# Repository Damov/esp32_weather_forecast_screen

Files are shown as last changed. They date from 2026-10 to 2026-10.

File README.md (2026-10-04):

# ESP32 weather forecast screen

A desktop weather display built around a 4-inch ESP32 touchscreen. It shows the local time, current weather and daily and hourly forecasts from Open-Meteo. The project includes Rust firmware for the Freenove FNK0103S display with an ESP32-WROOM-32E module, plus a 3D-printable enclosure and stand. An optional HLK-LD2410C radar detects presence to wake the screen.

The firmware was created using AI and agentic coding tools under human supervision.

<p align="center">
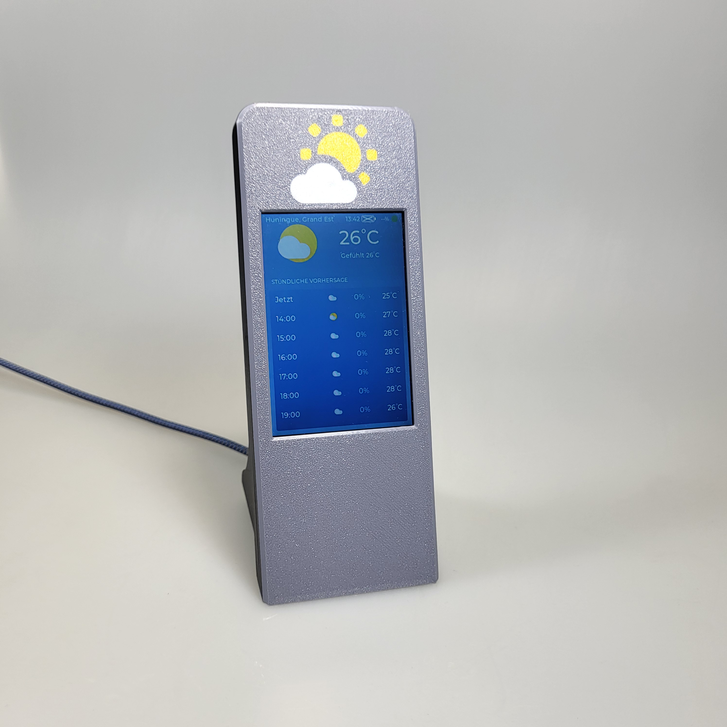
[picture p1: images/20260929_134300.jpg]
Weather display in its printed enclosure and stand

</p>

The photograph shows the assembled display running an older version of the firmware. The screenshots below show the current interface with example data.

## The interface

The 320 × 480 portrait display has a blue gradient background, white Montserrat text and darker blue weather panels. The Clock page combines an analogue dial with digital time and a local date. A rounded card below shows the weather symbol, current temperature and feels-like temperature.

The Week page shows today and the next six days, with weather symbols, precipitation probabilities and minimum and maximum temperatures. The Hours page shows the next seven hourly forecasts, with temperatures and precipitation probabilities. Both fit seven rows on the screen without scrolling. A settings gear and weather source credit sit at the bottom of each page.

<p align="center">
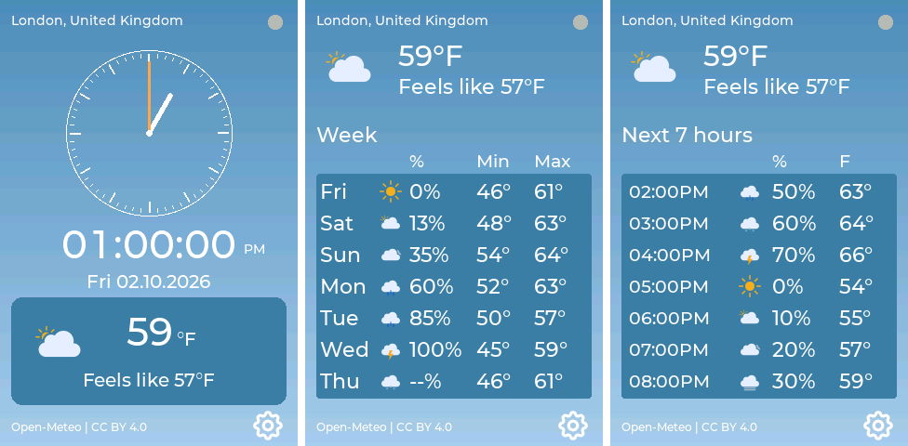
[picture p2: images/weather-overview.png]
Current Clock, Week and Hours pages, from left to right

</p>

## Printing, assembly and use

The [printing and assembly guide](printable_3D_model/README.md) includes the model files, parts list, print settings and radar wiring. The [illustrated user guide](USER_GUIDE.md) covers firmware installation, first startup, Wi-Fi, touchscreen controls, location search and settings.

## Building on Linux

Install [Rust with rustup](https://rustup.rs/) and the Linux host dependencies listed in the [esp-rs prerequisites](https://github.com/esp-rs/esp-idf-template#generate-the-project), including CMake, Ninja, Python and libclang. Then install the ESP32 toolchain and linker proxy:

```sh
cargo install espup --locked
espup install
cargo install ldproxy --locked
```

In each build shell, load the environment created by espup. Its default path is:

```sh
. "$HOME/export-esp.sh"
```

From the repository root, build the release firmware:

```sh
./build.sh
```

The project selects the `esp` Rust toolchain, the `xtensa-esp32-espidf` target and ESP-IDF `v5.5.5`. The first build needs internet access to download the SDK and tools. Use a shell without an `IDF_PATH` override so the pinned SDK is used.

The release ELF is written to `firmware/target/xtensa-esp32-espidf/release/weather-forecast-firmware`. The script forwards extra Cargo arguments, such as `./build.sh --locked` once `firmware/Cargo.lock` exists. It only builds the software.

See the [firmware README](firmware/README.md) for implementation details, host tests, asset generation and documentation previews. Installation steps are in the [user guide](USER_GUIDE.md#installing-the-firmware-under-linux).

To inspect or remove build output and temporary files:

```sh
./clean.sh --dry-run
./clean.sh
./clean.sh --all --dry-run
./clean.sh --all
```

Default cleanup removes Cargo build output, mutation-test output, Python bytecode caches, Rust backup files, `.pdb` files, and generated or old `sdkconfig` files. Tracked files, secrets, backups, and symlinks are preserved. `--all` also removes local `.embuild` SDK caches and the documented `/tmp/weather-wifi-preview` and `/tmp/weather-assets-venv` directories; the next build may download the SDK and tools again. Custom preview destinations and other files under `/tmp` are retained. The script works from any working directory and requires Bash and Git, without requiring Cargo. Run it when builds and preview generators are stopped.

## Building on Windows

**TODO:** To be written in near future!

## Licences and credits

The firmware source code is licensed under [MIT](LICENSE). Third-party components retain their own licences. This project was inspired by [Aura](https://github.com/Surrey-Homeware/Aura).

As of the MIT relicensing change on 4 October 2026, the project's own code is available under MIT. Earlier versions were published under GPL-3.0-only; rights already granted under that licence remain in effect. Third-party code and assets retain their respective licences.

- **Fonts:** [Montserrat](https://github.com/JulietaUla/Montserrat) by Julieta Ulanovsky and contributors (OFL-1.1), using [LVGL](https://github.com/lvgl/lvgl) font source material (MIT).
- **Symbols:** [Meteocons](https://github.com/basmilius/meteocons) by Bas Milius and [Tabler Icons](https://github.com/tabler/tabler-icons) by Paweł Kuna (MIT).
- **Display:** ST7796 initialization adapted from [TFT_eSPI](https://github.com/Bodmer/TFT_eSPI/tree/V2.5.43) by Bodmer (MIT/BSD).
- **Platform:** [ESP-IDF](https://github.com/espressif/esp-idf/tree/v5.5.5) and Rust libraries listed in the [dated dependency CSV](docs/third-party-rust-2026-10-04.csv). ESP32 Wi-Fi and PHY require precompiled Espressif libraries without publicly available complete implementation source.
- **HTTPS certificates:** [Mozilla CA certificate data](https://curl.se/docs/caextract.html) (MPL-2.0).
- **Weather and locations:** [Open-Meteo](https://open-meteo.com/) and [GeoNames](https://www.geonames.org/) (data attribution under CC BY 4.0). Open-Meteo's free API has [non-commercial service terms](https://open-meteo.com/en/terms).

See the [third-party declaration dated 4 October 2026](docs/third-party-declaration-2026-10-04.md) for sources, versions, licences and attribution details.

Binary firmware distributions must include the accompanying third-party notices and required source materials. See the [release licensing workflow](docs/FIRMWARE_RELEASE_LICENSES.md) for the collected notices, offline checks, local packaging and automatic GitHub releases on version tags.

## TODO

- [ ] Reuse the display’s BOOT button to trigger screen recalibration.
- [ ] Add a complete factory reset capability using the display’s RST button.

# Disclaimer

<b>This project and all associated files, documentation, and source code are provided “as is” without any express or implied warranties, including but not limited to the implied warranties of merchantability, fitness for a particular purpose, and non‑infringement. The author and contributors of this repository assume no responsibility or liability for any direct, indirect, incidental, or consequential damages that may occur through the use, modification, or distribution of the software and hardware designs contained herein. This includes, but is not limited to, hardware damage, data loss, malfunctioning devices, or personal injury that may arise from incorrect wiring, improper configuration, or misuse of the provided code and documentation. Users are encouraged to review, test, and verify all code before deploying it on any system. If you choose to use this project, you do so entirely at your own risk. By downloading, copying, modifying, or using any part of this project, you acknowledge that you have read, understood, and agree to this disclaimer.

The HLK-LD2410C radar module’s CE status is unknown to this project. The existence of an EU declaration of conformity or US regulatory compliance documentation has not been verified. Check your local laws and regulatory requirements before using the radar. Use it at your own risk.</b>

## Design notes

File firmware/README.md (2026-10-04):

# Firmware development

This directory contains the Rust application, using ESP-IDF with standard-library support. See the [main README](../README.md#building-on-linux) for the Linux build and the [user guide](../USER_GUIDE.md) for installation and device operation. The [assembly guide](../printable_3D_model/README.md) covers physical wiring.

Run the commands in this document from the repository root.

For binary distribution, use the [release licensing workflow](../docs/FIRMWARE_RELEASE_LICENSES.md) to check the original third-party notices and package them with the firmware.

## Build layout under Linux

Use `./build.sh` for device builds. It resolves `firmware/partitions.csv` to an absolute path in `firmware/target/esp32-partitions.sdkconfig`. That generated file supplies only the partition filename. `firmware/sdkconfig.defaults` supplies the remaining settings. Host tests and previews can use Cargo directly.

The build script forwards Cargo arguments and can be invoked by its path from another directory. Keep `firmware/Cargo.lock` in Git once generated for reproducible dependency resolution. Assets are checked in, so a normal device build does not need the font or icon conversion tools.

## Settings storage and compatibility

The versioned JSON profile is stored in NVS namespace `app_settings`, key `profile`, separately from Wi-Fi credentials and `touch_cal`. If no profile exists, the firmware reads compatible values from the legacy `weather` namespace without modifying its keys. The first preference change saves the imported profile. An imported location with no timezone is resolved online. No night schedule is applied until its timezone is known. Unreadable profiles show an error and disable preference writes without erasing storage.

Older version-1 profiles without the presence-wake field default to enabled. The legacy `weather/wakePresence` value is imported when available. Disabling wake changes backlight behaviour without stopping sensing or indicator updates.

## Backlight and time scheduling

**Screen off after** offers Never, 1, 5, 10, or 30 minutes. Inactivity uses a monotonic timer: touch, enabled radar presence, and calibration restart it. Background Wi-Fi traffic, clock updates, and HTTP responses do not. Calibration also keeps the backlight at least half brightness. Changing the timeout restarts the countdown. Old profiles without `sleep_minutes` default to five minutes. Supported timeout values are imported from the legacy `weather/standbyMinutes` key without modifying it.

When the timeout expires, only the LCD backlight turns off. The ESP32, LCD controller, Wi-Fi, radar, clock, and forecast worker keep running, and the screen contents continue updating. Touch or enabled presence restores the saved brightness without restarting the firmware, reconnecting Wi-Fi, or changing the selected page. The waking touch is consumed until release so it does not activate a button. This keeps information immediately available, with higher power consumption than deep sleep. A failed backlight-off write leaves the screen on and retries after 60 seconds. A failed restore leaves it off and allows another activity to retry.

Night mode defines 22:00–06:00 in the selected location's IANA timezone, including DST. With a finite timeout, the same inactivity interval applies day and night. With **Never**, inactivity blanking is disabled, but an enabled night schedule can still turn the backlight off. A touch or enabled presence overrides that night's schedule until the next daytime period is observed. SNTP supplies UTC time after Wi-Fi connects. The night schedule waits for synchronised time and a valid timezone. A dark screen stays dark after 06:00 until touch or enabled presence restores it. The stored `sleep_minutes` key and profile version remain unchanged for compatibility.

## Location search

Search runs in a worker over certificate-verified HTTPS, requesting up to 15 results in the selected language. Select a result and tap **Save** to store its name, coordinates, and IANA timezone. Responses are limited to 32 KiB. The screen times out after 10 seconds and ignores cancelled, stale, or late results. Searches require Wi-Fi and synchronised time. The saved location, timezone, units, language, and clock format apply to all weather views.

## Weather fetching and rendering

Search results save an optional `compact_name` for the city-and-country label. Older profiles remain compatible. For three-part names, weather pages omit the intermediate region. Single names remain unchanged when country information is unavailable. Search and Settings keep the full location name.

All pages use the saved location's IANA timezone, including daylight-saving changes, and honour Celsius/Fahrenheit, 12/24-hour time, and the eight supported languages. The clock waits for synchronised time and a known timezone. It never substitutes UTC for an unresolved local timezone. The six time digits use fixed-width cells centred as one group, so changing digits never shifts the other digits or colons. Seconds repaint only the clock region, without repainting weather, presence, or buttons. Updates compare the previous and new clock contents in two reusable RGB565 strip buffers (18.5 KiB total). Only runs of actually changed pixels are sent to the LCD. Unchanged content causes no display writes. On the Clock page, forecast and status updates also compare finished pixels, reusing the same buffers for the weather card and status line. These updates leave the clocks, location, attribution and settings gear untouched. Week and Hours use the same differential updates for their current weather, status, and seven forecast rows, including hour and date rollovers. Their tables use the Clock weather card's darker blue. Text uses 19/22/31px fonts, with seven entries still visible without scrolling. The shared buffers keep the same 18.5 KiB allocation. Page changes and returns from Settings seed a new snapshot after a complete draw. Failed transfers invalidate the affected snapshot so a subsequent attempt restores that region. There is no visible background-clear pass during these updates and no PSRAM requirement. Settings retains its minute-only clock updates. Clock and HTTP traffic do not reset the inactivity timer.

Forecasts use the [Open-Meteo forecast API](https://open-meteo.com/en/docs) over certificate-verified HTTPS in the existing background worker. The firmware refreshes every ten minutes, retries errors after sixty seconds, and refreshes on reconnection or location change. Responses are limited to 32 KiB and HTTP operations to ten seconds, with a thirty-second application deadline allowing for a queued operation. Eight days of data are fetched to cover midnight rollover, while only seven daily and seven hourly entries are displayed. Temperatures are cached in Celsius and converted locally when units change.

Loading and failed requests have visible messages. Missing values show `--`. Unknown weather codes use a neutral unavailable symbol. Failed refreshes retain the previous same-location forecast and mark it outdated. Data also becomes outdated after twenty minutes without a successful refresh. Expired dates/hours are excluded, and unavailable future entries show placeholders. Changing the location clears the old forecast and ignores late responses. Forecasts are held only in RAM. If Wi-Fi drops, the existing connection status screen returns and reconnects. The selected weather page returns after connection succeeds.

## Weather symbols and UI icons

The white settings gear uses Tabler Icons' **settings** SVG by Paweł Kuna, under the MIT licence. The pinned source, revision, checksum, copyright and full licence are in `firmware/assets/ui/`. `tools/generate_ui_icons.py --check` verifies the generated alpha mask. See [Tabler Icons](https://github.com/tabler/tabler-icons). This symbol licence is separate from the CC BY 4.0 weather-data attribution.

Weather symbols are the static **flat Meteocons** collection by **Bas Milius**: [source repository](https://github.com/basmilius/meteocons), pinned npm package [`@meteocons/svg-static` 0.1.0](https://www.npmjs.com/package/@meteocons/svg-static/v/0.1.0).

**Licence: MIT**, with copyright **(c) 2020-present Bas Milius**. The licence permits free use, modification, embedding, and redistribution, including commercial use, provided the copyright and permission notice are retained.

The symbols retain their MIT licence independently of the MIT firmware. The complete [MIT licence](assets/weather/MIT.txt), [attribution and conversion notice](assets/weather/NOTICE.txt), [source/version/integrity manifest](assets/weather/sources.json), and [SHA-256 asset checksums](assets/weather/checksums.json) are included. Retain MIT.txt and NOTICE.txt with source and binary releases, along with the existing firmware and font notices. Credits do not imply endorsement.

The original SVG subset is retained under `firmware/assets/weather/svg/`. Thirteen symbols cover clear day/night, partly cloudy day/night, overcast, fog, drizzle, freezing precipitation, rain, snow, thunderstorms, thunderstorms with hail, and unavailable conditions. Symbols are converted to 32px forecast and 72px current-weather bitmaps with RGB565 colour and alpha transparency. Their shapes are preserved, and no runtime icon download or SVG library is required.

Regenerate or check assets using **CairoSVG 2.7.1**, **Cairo 1.16.0**, and **Pillow 9.0.1** (Cairo is a system library):

```sh
python3 -m venv --system-site-packages /tmp/weather-assets-venv
/tmp/weather-assets-venv/bin/pip install CairoSVG==2.7.1 Pillow==9.0.1
/tmp/weather-assets-venv/bin/python tools/generate_weather_icons.py
/tmp/weather-assets-venv/bin/python tools/generate_weather_icons.py --check
```

The converter verifies the archive's pinned SHA-512 integrity before reading it. CairoSVG and Pillow are build-time conversion tools with their own licences. They are not linked into the firmware. The clock adds a 42px Montserrat numeric subset under the existing OFL-1.1 font licence, generated by the font tool.

## HLK-LD2410C radar

**The HLK-LD2410C radar module’s CE status is unknown to this project. The existence of an EU declaration of conformity or US regulatory compliance documentation has not been verified. Check your local laws and regulatory requirements before using the radar. Use it at your own risk.**

The Rust receiver implements [Hi-Link’s LD2410C serial protocol V1.09](https://r0.hlktech.com/download/HLK-LD2410C-24G/1/LD2410C%20%E4%B8%B2%E5%8F%A3%E9%80%9A%E4%BF%A1%E5%8D%8F%E8%AE%AE%20V1.09.pdf). Firmware code is licensed under MIT.

| Radar connection | ESP32/display connection |
| --- | --- |
| TX | GPIO35 / GP35, UART1 receive |
| OUT | GPIO32 / P4 SDA, active-high presence input |
| RX | Unconnected. This firmware sends no sensor commands |
| GND | Common display ground |
| VCC | Existing regulated 5 V supply with capacity above 200 mA |

Sensor data lines are 3.3 V logic. UART1 runs at the sensor's factory setting of **256000 baud, 8N1**, leaving the CH340 USB connection on UART0 available for logs and flashing. GPIO39 belongs to the touch controller. UART0 and GPIO39 are not used for radar. The driver initialises after startup calibration and reads in bounded nonblocking batches from a 4096-byte receive buffer. No additional radar library or device configuration is required.

Both basic and engineering reports provide moving/stationary target flags, respective distances in centimetres, energy values, and detection distance. A fixed 64-byte parser validates framing and resynchronises after malformed data. After one second without a valid report, UART connectivity and all measurements are cleared. OUT is evaluated independently: an asserted OUT or a fresh positive UART report counts as presence. An inactive OUT does not override a positive UART report. Empty nonblocking reads retain partial frames. UART read errors clear their measurements and are retried on subsequent loops. Initialisation errors are logged without stopping the UI, and an available OUT input continues to work even if UART initialisation fails.

Presence from either a fresh positive UART report or OUT drives the saved wake preference. Sensing continues when wake is disabled and while the backlight is off. See the [user guide](../USER_GUIDE.md#presence-indicator) for indicator meanings
and operation.

## Appearance, fonts, and attribution

The UI uses a vertical gradient from `#4C8CB9` to `#A6CDEC`, white text, `#5E9BC8` panels, and 4-pixel rounded corners on buttons, keyboard keys, and input fields. Wi-Fi, settings, startup, and calibration screens share the same renderer and theme.

The original font is **Montserrat**, initially designed by **Julieta Ulanovsky** and developed by the Montserrat project contributors. Its origin repository is [JulietaUla/Montserrat](https://github.com/JulietaUla/Montserrat), and its published family page is [Montserrat on Google Fonts](https://fonts.google.com/specimen/Montserrat).

The firmware combines Montserrat Medium for standard characters and Montserrat Light for additional Latin characters, with 20-pixel headings, 14-pixel body/control text, and 12-pixel secondary labels, plus a 42-pixel numeric subset for the seconds clock. Week and Hours use complete 19/22/31-pixel Montserrat Medium subsets rasterised from the pinned TTF, including localised glyphs.

**Font licence: SIL Open Font Licence 1.1 (OFL-1.1).** The font assets retain this licence independently of the firmware's **MIT** licence. The OFL permits free use, embedding, modification, and redistribution, including with commercial software, subject to its conditions. It does not permit selling the font alone. The complete [OFL and copyright notice](assets/fonts/OFL.txt), [font attribution and modifications](assets/fonts/NOTICE.txt), and [LVGL MIT notice](assets/fonts/LVGL-MIT.txt) are included in this repository. Distribute these three files alongside the firmware, including binary releases. Retain the firmware code's separate MIT copyright and permission notice.

The converted bitmap assets are named **Weather Display UI Subset**, distinguishing them from the original font. The selected OFL notice declares no Reserved Font Names. The conversion preserves the LVGL ASCII glyphs and rasterises all non-ASCII UI glyphs directly from the pinned Montserrat Light TTF. Coverage is stored at four bits per pixel with sparse kerning pairs. The UI subset includes 216 characters: printable ASCII, 47 additional Latin letters and symbols, and all 66 uppercase/lowercase Russian letters, including Ё/ё, plus the eight additional Ukrainian letters Ґ/ґ, Є/є, І/і, and Ї/ї. The forecast subsets include 206 characters covering ASCII, localised messages, location-entry accents, and the complete Russian and Ukrainian alphabets. Other characters render as `?`. Font Awesome and weather icons are not included in this subset. Credits identify the sources and do not imply their authors endorse this project.

Reproducible source versions:

- [LVGL 9.2.2 fallback fonts](https://github.com/lvgl/lvgl/tree/7f07a129e8d77f4984fff8e623fd5be18ff42e74/src/font),
  commit `7f07a129e8d77f4984fff8e623fd5be18ff42e74`.
- [Montserrat Light TTF](https://github.com/JulietaUla/Montserrat/blob/555facfb2a18c72c3c0380f0d9c0f060453a9058/fonts/ttf/Montserrat-Light.ttf),
  commit `555facfb2a18c72c3c0380f0d9c0f060453a9058`, under the same OFL-1.1 notice.
- [Forecast Montserrat Medium TTF](https://github.com/JulietaUla/Montserrat/blob/555facfb2a18c72c3c0380f0d9c0f060453a9058/fonts/ttf/Montserrat-Medium.ttf),
  commit `555facfb2a18c72c3c0380f0d9c0f060453a9058`, under the same OFL-1.1 notice.
- [Published Montserrat OFL notice](https://github.com/google/fonts/blob/9710da1eacb3be272583c3224dcb70f9da6eadbb/ofl/montserrat/OFL.txt),
  Google Fonts commit `9710da1eacb3be272583c3224dcb70f9da6eadbb`.

The [font source manifest](assets/fonts/sources.json) records exact source URLs and SHA-256 checksums. Regenerate or verify the checked-in assets with Python with **Pillow 9.0.1 and FreeType 2.11.1** (both versions are checked):

```sh
python3 tools/generate_fonts.py
python3 tools/generate_fonts.py --check
```

ASCII and clock glyphs retain their original LVGL raster shapes. Non-ASCII UI glyphs are rasterised from Montserrat Light, and forecast glyphs from Montserrat Medium. Pillow is needed only for asset generation. Its [source and licence](https://github.com/python-pillow/Pillow/blob/9.0.1/LICENSE) are separate from the font licence.

The converter downloads pinned sources only on a cache miss and verifies their checksums. Font assets are embedded in flash. No font downloads or runtime font library are required on the device. Rendering uses a small text band rather than a full-screen framebuffer and requires no PSRAM.

Settings dependencies are pinned by `firmware/Cargo.lock`. The direct libraries [Serde](https://github.com/serde-rs/serde), [serde_json](https://github.com/serde-rs/json), [Chrono](https://github.com/chronotope/chrono), and [Chrono-TZ](https://github.com/chronotope/chrono-tz) offer MIT or Apache-2.0 licensing. Their upstream copyright and licence files are retained under [dependency notices](assets/licenses). Retain applicable notices when distributing the firmware. Chrono-TZ uses public-domain timezone data.

## Display and touch setup

The board uses classic ESP32 with 4 MiB flash, matching the chip identification from the verified original device backup. Its 4-inch ST7796 display uses SPI2 (HSPI): MOSI 13, MISO 12, SCLK 14, CS 15, DC 2, and active-high backlight 27. The XPT2046-compatible resistive touchscreen shares that bus with CS 33. Display transfers run at 40 MHz and touch transfers at 2.5 MHz, with separate chip selects. The display uses Freenove's ST7796 initialisation sequence, BGR colours, and portrait orientation. Software reset and a small SPI rendering buffer avoid needing PSRAM. See the [Freenove ESP32 Display resources](https://github.com/Freenove/Freenove_ESP32_Display).

Calibration is saved in NVS namespace `touch_cal`, key `portrait`. Missing, malformed or incompatible calibration starts guided setup. Storage failures report an error without erasing NVS. Touch filtering, pressure checks and press/release debounce produce one action per press. Calibration instructions are in the [user guide](../USER_GUIDE.md#recalibrating-touch).

The tracked partition table matches the original backup:

| Partition | Offset | Size |
| --- | --- | --- |
| NVS | `0x9000` | `0x5000` |
| OTA metadata | `0xe000` | `0x2000` |
| Application (`app0`, OTA slot 0) | `0x10000` | `0x300000` |
| SPIFFS | `0x310000` | `0xe0000` |
| Coredump | `0x3f0000` | `0x10000` |

No OTA update feature is implemented. Keeping these boundaries permits reuse of existing Wi-Fi settings and filesystem contents without a storage migration.

## Wi-Fi credential storage

SSID and password are stored **unencrypted** through ESP-IDF's native Wi-Fi configuration persistence. The SDK owns the NVS keys. This firmware does not use custom credential records or require HMAC keys or eFuse provisioning. Anyone able to read the device's flash can recover its saved password.

At startup, the SDK loads the existing station profile before connection settings are changed. Existing legacy settings can be reused when the original NVS partition is retained and the credentials meet the supported network/password requirements. An empty profile opens Wi-Fi setup. Invalid or unsupported profiles display a storage error without erasing saved data.

Connection attempts, scans, cancellation, and driver cleanup use RAM storage. Only after obtaining an IP address does the worker switch to flash storage and save the active station configuration, then restore RAM storage even if saving fails. Save errors disconnect the candidate and retain the previous selection in memory. Native SDK persistence does not provide a two-slot replacement guarantee across failed writes or power loss.

Password entry remains masked by default. Application password buffers and native configuration buffers are zeroised, and passwords are excluded from application logs. The Wi-Fi driver necessarily retains its active password in RAM. NVS initialisation never automatically erases a full, corrupt, or incompatible partition. Previously encrypted application profiles are not migrated or erased by this change. No scripts burn eFuses or erase/flash the device automatically.

The original full-flash backup remains separate from this port. This firmware requires the confirmed Freenove 4-inch ESP32 configuration. The ESP32-WROOM-32E module alone does not identify another manufacturer's display wiring.

## Tests and hardware acceptance

Run hardware-independent tests with the host Rust toolchain:

```sh
cargo +stable test --manifest-path firmware/Cargo.toml \
  --target x86_64-unknown-linux-gnu --no-default-features --lib
```

These tests exercise page transitions, keyboard characters and hit targets, stale events, reconnect deadlines, IP timeouts, cancellation, scan errors, and fake network/storage failures. They also verify that credentials are not saved before an IP address is obtained and that successful saves survive a simulated restart. Touch tests cover corner/centre mapping, swapped/inverted axes, invalid calibration, rejected noise and pressure, calibration persistence, and debounce. Theme tests verify proportional font metrics, kerning, glyph coverage, pixel-based wrapping and clipping, antialias blending, gradient endpoints, and rounded corners. Settings tests cover persistence and rollback, legacy settings imports, timezone/DST behaviour, screen-off deadlines, search bounds and stale results, confirmation flows, calibration timeouts and cancellation, and all language control layouts. Ukrainian tests cover the complete location keyboard, alphabet switching, search language and selection persistence. Compatibility tests cover the English fallback for unsupported legacy language selections. Radar tests exercise both report types and all target states, fragmentation, damaged frames, resynchronisation, timeout, OUT fallback, profile compatibility, and switch saving/rollback. Screen tests cover timeout boundaries, calibration and activity, Never and night overrides, staying dark after morning, consumed touches, restored brightness, and failed backlight writes with retry deadlines. Weather tests cover bounded parsing, missing values, unknown codes, refresh/retry deadlines, stale location responses, DST and fractional-offset timezones, and page navigation across settings and connection recovery. The preview tests verify that clipped settings-clock, seconds-clock, and presence updates match complete renders while leaving every other pixel unchanged. Forecast update tests cover all three views and every language/unit combination, assert that exactly the changed pixels are transferred, and verify no writes for unchanged contents and recovery after failed transfers. Daily probability tests cover fractional means, 0/100%, missing fields and null values, invalid ranges and array lengths. Probability-only updates are confined to the Week precipitation column. Larger-font checks cover all translated headings, numeric values, and hourly time labels without dates or timezone text. Rollover previews exercise midnight and both DST transitions in 12/24-hour formats. They also verify clock and forecast updates while dark and preservation of the current page and frame on wake.

```sh
cargo +stable test --manifest-path firmware/Cargo.toml \
  --target x86_64-unknown-linux-gnu --no-default-features --example preview
```

On the confirmed board, verify first-boot guided calibration, centre alignment, reboot persistence, and BOOT-triggered recalibration. Check red/green/blue, black, and white display output. Then verify all four screen corners, every keyboard mode, network paging, invalid passwords, successful setup, reboot persistence, turning the hotspot off/on, and replacing a network unsuccessfully. Verify loading an existing legacy profile while preserving its NVS partition. Inspect serial logs using a disposable test password to confirm it is never logged. A flash dump should contain the saved password in plaintext. Test storage errors and power loss during replacement. Real Wi-Fi interoperability, native persistence, and touch alignment require hardware testing.

Generate previews using the same renderer as the firmware:

```sh
cargo +stable run --manifest-path firmware/Cargo.toml \
  --target x86_64-unknown-linux-gnu --no-default-features --example preview
```

The example writes PPM images to `/tmp/weather-wifi-preview/`. An optional directory argument changes the destination. The previews cover every Wi-Fi page, keyboard modes, disabled controls, long and accented network names, password display, startup, and calibration, plus eight settings overlays in every supported language and three radar states per language. Weather previews include all three pages in every language, with ready, loading, error, outdated, night, and long-location scenarios. Russian and Ukrainian previews also cover Wi-Fi, startup, calibration, and all five city keyboard modes. Two additional English Wi-Fi previews provide concise examples for the user guide. Preview passwords and weather data are synthetic.

Hardware acceptance for backlight blanking requires flashing this build: verify each finite timeout, Never with night mode on/off, remaining dark after 06:00, touch wake without activating the underlying button, presence enabled/disabled, and calibration preventing blanking. Check that clock and forecasts update while dark and that wake restores the same page without a reboot or Wi-Fi reconnect. The target is under 100 ms from valid touch or presence to visible information. This latency requires measurement on the board.

Weather hardware acceptance requires the built firmware on the confirmed board: verify seconds without full-screen flicker, readable seven-row forecasts, tap cycling without triggering footer controls, settings changes, midnight/DST labels, responsive touch during HTTP requests, Wi-Fi loss/reconnection, and retained backlight-off/wake behaviour. Forecast unit tests and previews do not replace these checks.

## Refresh the documentation screenshots

After regenerating fonts when translations or keyboard characters change, render the UI and export the curated PNG screenshots used in the guide:

```sh
cargo +stable run --manifest-path firmware/Cargo.toml \
  --target x86_64-unknown-linux-gnu --no-default-features --example preview
python3 tools/generate_readme_images.py /tmp/weather-wifi-preview
```

The exporter uses Pillow to convert the renderer's PPM output without resizing and combines the three English weather pages into the README overview.

# Disclaimer

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

The HLK-LD2410C radar module’s CE status is unknown to this project. The existence of an EU declaration of conformity or US regulatory compliance documentation has not been verified. Check your local laws and regulatory requirements before using the radar. Use it at your own risk.</b>

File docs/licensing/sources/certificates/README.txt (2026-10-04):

Certificate source material (MPL-2.0)

The bundled cacrt_all.pem is the exact input to ESP-IDF's certificate-bundle
conversion. Its header preserves the Mozilla attribution, extraction date,
upstream source reference and conversion provenance. gen_crt_bundle.py and
sdkconfig.json describe the conversion and selection used by this firmware.
Modify the PEM input and rebuild the firmware to change its trust store.
These source materials remain available under MPL-2.0; the project's MIT
license does not replace their terms. No additional restriction is imposed
on recipients' rights to this material.

Mozilla original certificate data: https://hg.mozilla.org/projects/nss/file/tip/lib/ckfw/builtins/certdata.txt
PEM extraction tool and information: https://curl.se/docs/caextract.html

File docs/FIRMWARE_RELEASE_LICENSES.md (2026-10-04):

# Firmware release licenses

The project's own code is MIT-licensed. Embedded third-party software, fonts,
icons and certificate data retain their own licenses. Distribute firmware with
its accompanying license materials; a bare `.bin` is not the documented release
format. This workflow checks evidence coverage and integrity, not legal
compliance, copyright ownership or permission to use online services.

## Collected evidence

[Third-party notices](licensing/THIRD-PARTY-NOTICES.txt) describe the components and
include their original notices and source origins. [The manifest](licensing/manifest.json) records
versions, selected license alternatives, source origins and SHA-256 checksums.
The format-3 manifest also records the application ELF hash and application
source/configuration hashes; packaging rejects a different ELF or changed inputs.
The collection covers the ESP32 target's normal dependencies and relevant
code-generation providers, currently 67 package versions. Build/test-only
packages and unrelated platforms are excluded. Macro providers are retained
conservatively when their generated code could be included; the timestamp-only
`build-time` macro is explicitly excluded. Target dependencies can still be
optimized out; this is target graph coverage rather than a claim that every
package contributes bytes to the binary.

SDK coverage uses the application and bootloader memory maps, excluding the
map's discarded sections and cross-reference table. Original notices and source
headers are retained for the relevant components and compilation inputs. Only
compiler runtime notices are included, not licenses for the compiler's build
tools. The Rust standard-library report and notices within a relevant SDK
component can conservatively cover additional platform variants.

License texts and attributions are combined into one readable text document.
Identical bodies are stored once while preserving every associated evidence
label and source origin. The manifest records hashes and byte ranges for the
original notice bodies. File-level upstream notices take precedence over
summaries.

MIT is selected where offered by Rust dependencies, with supplemental Unicode
notices retained. Other selections are recorded per package. Mbed TLS uses its
Apache-2.0 option. GCC runtime material retains its original terms and the GCC
Runtime Library Exception; the standard free Rust/GCC build process must remain
eligible for that exception.

Most notices come from checksum-verified crate archives. Missing notices are
retrieved from immutable upstream revisions identified by the package's VCS
metadata. `void` 1.0.2 declares MIT in its README, with the author's name, but
supplies no standalone copyright notice. Its original declarations and standard
MIT terms are preserved with an explicit evidence note. No copyright holder or
year has been invented. This documents available evidence, not a certification
of rights.

Certificate material remains MPL-2.0. The exact SDK PEM source input, converter,
build configuration, MPL text and provenance are retained under
[certificate sources](licensing/sources/certificates/README.txt). Recipients can
modify that input and rebuild the firmware. Preserve these materials and their
notices when redistributing. The project's MIT license does not replace MPL.

Open-Meteo and GeoNames data attribution remains CC BY 4.0. The free Open-Meteo
service is for non-commercial use; MIT does not grant commercial API access.
Freenove's other resources retain their own terms and are not covered by the
project's MIT license.

## Check without changing files

From the repository root:

```sh
python3 tools/license_release.py check
python3 -m unittest discover -s tools/tests -p 'test_license_release.py'
```

`check` needs no network, SDK, compiler or additional Python packages. It checks
the reviewed inputs and retained evidence; it does not rebuild the firmware.
Missing or altered evidence and changed dependency/configuration inputs fail.

## Refresh the evidence after a reviewed change

First review dependency/license changes and build with `./build.sh --locked`.
Load your normal Rust/ESP environment as described in the main README. The SDK
build directory is the `out/build` directory below the current `esp-idf-sys`
build output. Its `project_description.json` gives the compiler path. Supply the
compiler distribution root containing both `bin/` and `share/licenses/`.
For the current build layout:

```sh
python3 tools/license_release.py update \
  --idf-build-dir firmware/target/xtensa-esp32-espidf/release/build/esp-idf-sys-039f6d788fc2a729/out/build \
  --toolchain-dir firmware/.embuild/espressif/tools/xtensa-esp-elf/esp-14.2.0_20260121/xtensa-esp-elf \
  --firmware-dir firmware/target/xtensa-esp32-espidf/release
python3 tools/license_release.py check
```

Build hashes and toolchain directory names can change; use the paths belonging
to your build. `update` explicitly uses the network and atomically prepares a
complete replacement collection before installing it. It verifies the reviewed
ESP-IDF/submodule revisions and crate checksums. It does not silently accept a
new lockfile: update and review the dependency inventory first. The checked-in `licensing-policy.json` pins the reviewed SDK/compiler/Rust
versions, target-package selection and explicit notice/code-generation
exceptions. A new SDK or runtime version requires review of its actual licensing terms and an explicit policy
update before refreshing the evidence. Review the resulting diff and original
notices, not just the generated success message.

## Package the existing firmware images

Generate `weather-forecast-firmware.bin` from the Rust ELF using the existing
[user-guide instructions](../USER_GUIDE.md#installing-the-firmware-under-linux).
The firmware directory must contain that ELF plus `bootloader.bin`,
`partition-table.bin` and `weather-forecast-firmware.bin`. Use the ESP-IDF Python
environment containing esptool:

```sh
python3 tools/license_release.py package \
  --idf-build-dir firmware/target/xtensa-esp32-espidf/release/build/esp-idf-sys-039f6d788fc2a729/out/build \
  --toolchain-dir firmware/.embuild/espressif/tools/xtensa-esp-elf/esp-14.2.0_20260121/xtensa-esp-elf \
  --firmware-dir firmware/target/xtensa-esp32-espidf/release \
  --esptool-python firmware/.embuild/espressif/python_env/idf5.5_py3.10_env/bin/python \
  --version 0.1.0 \
  --output-dir firmware/target/license-release
```

This creates `weather-forecast-0.1.0.zip` and `.tar.gz`, each containing the same
three flash images, project license, third-party evidence, certificate sources,
standalone installation instructions, build provenance and `SHA256SUMS`.
Existing output archives are not overwritten. Nothing is flashed or published.

Packaging verifies SDK/runtime evidence, compares the bootloader and partition
table with their build outputs, and regenerates the application image from the
Rust ELF in a temporary directory to verify its contents. ESP-IDF's intermediate
`libespidf.bin` is never substituted for the Rust firmware. The classic ESP32,
4 MiB flash and recorded partition configuration are the supported layout.

Publish complete archives as the firmware downloads. If distributing images
separately, provide the same accompanying license and source materials and make
them clearly available to recipients. Release wording should say:

> Project code is MIT-licensed. Included third-party components retain their
> respective licenses; see the accompanying license files.

## Automatic GitHub builds and releases

The `Firmware release` GitHub Actions workflow builds on pushed version tags
such as `v0.1.0` or `v0.1.0-rc.1`. Other `v*` tags fail validation. A successful
tag build publishes complete firmware ZIP/tar.gz packages and an external
`SHA256SUMS` file. GitHub supplies the tag's source ZIP and tar.gz automatically.
The firmware archives contain the three images, installation instructions,
notices, certificate sources and build provenance. Separate bare binary assets
are not published.

Use Actions → Firmware release → Run workflow for the first validation run.
Select a branch containing the workflow. Manual runs upload test artifacts for
30 days and never publish a release. The workflow must exist on GitHub's default
branch for the manual trigger to be available. Ordinary branch pushes do not
start firmware builds. No personal access token is required; only the tag-only
publication job receives repository contents write permission.

CI installs pinned ESP Rust 1.97.0.0 and builds with `--locked`, without caching
application outputs. `tools/ci_release.py` discovers the active build paths from
Cargo output. It collects evidence in a temporary directory after compilation
and packages only the recorded ELF. All licensing policy checks still apply;
new dependency or SDK/runtime versions require review. Repository files are not
rewritten. All license-tool commands accept `--collection-dir` to select a
build-specific collection; the default remains `docs/licensing`.

Source and ELF hashes record the build supplied at collection time. They are
integrity evidence, not proof that an arbitrary manually supplied ELF was built
from those sources. CI establishes that association by running the locked build
and collecting immediately from its reported application artifact.

The release stays a draft until both archives and checksums have uploaded.
Existing releases are never overwritten. If an upload fails after draft creation,
inspect the draft and delete it manually before retrying; the workflow will not
replace assets automatically. A first hosted manual run is still needed to
validate GitHub runner setup before creating a release tag.

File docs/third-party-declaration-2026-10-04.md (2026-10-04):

# Third-party sources and licences declaration

ESP32 weather forecast screen

**Declaration date:** 2026-10-04

This declaration identifies third-party software, visual assets and data
used by the project or its build tools. The project's firmware source code
is licensed under MIT. Third-party components retain their own
copyright notices and licence terms. This declaration provides attribution
and source references; it does not replace the upstream licence texts or
grant additional permissions.

The [collected release notices](licensing/THIRD-PARTY-NOTICES.txt) retain original
licence and copyright texts, supplemental source notices and certificate source
materials. The [release workflow](FIRMWARE_RELEASE_LICENSES.md) explains offline
validation and distribution packaging; its checks are not legal certification.

## Fonts

Montserrat was originally designed by Julieta Ulanovsky and is developed
by the Montserrat project contributors. The display uses modified bitmap
subsets of Montserrat Light and Medium at 12, 14, 19, 20, 22, 31 and 42 pixels.
These assets are named Weather Display UI Subset and remain under the SIL
Open Font Licence 1.1. Their source includes the Montserrat project at
commit 555facfb2a18c72c3c0380f0d9c0f060453a9058 and LVGL 9.2.2 font files
at commit 7f07a129e8d77f4984fff8e623fd5be18ff42e74. LVGL source material
has an additional MIT notice. The font subsets contain no Font Awesome
or weather icon glyphs.

Sources:

- [Montserrat](https://github.com/JulietaUla/Montserrat)
- [LVGL font sources](https://github.com/lvgl/lvgl/tree/7f07a129e8d77f4984fff8e623fd5be18ff42e74/src/font)

The exact font sources and checksums are in [firmware/assets/fonts/sources.json](../firmware/assets/fonts/sources.json).
Attribution, modification details and licence texts are in that directory's
[NOTICE.txt](../firmware/assets/fonts/NOTICE.txt), [OFL.txt](../firmware/assets/fonts/OFL.txt) and [LVGL-MIT.txt](../firmware/assets/fonts/LVGL-MIT.txt). Retain those notices with distributions
of the font assets. Modified fonts remain under OFL-1.1; the project's MIT
licence does not replace the font licence.

## Weather and interface symbols

Weather symbols are the flat Meteocons collection by Bas Milius, sourced
from @meteocons/svg-static version 0.1.0 under MIT. Thirteen SVG symbols
are converted to bitmap assets at 32 and 72 pixels, using RGB565 colour
and alpha coverage. Source SVGs, attribution, checksums and the MIT text
are retained under [firmware/assets/weather/](../firmware/assets/weather/).

Source: [Meteocons](https://github.com/basmilius/meteocons)

The settings gear is the settings SVG from Tabler Icons by Paweł Kuna,
revision 74929e50416e2b7c0abb8368cdc74bdcb2560ab6, under MIT. It is converted
to a 38-pixel alpha mask. The SVG, source metadata, attribution and licence
are retained under [firmware/assets/ui/](../firmware/assets/ui/).

Source: [Tabler Icons](https://github.com/tabler/tabler-icons)

## Display initialization

The ST7796 initialization sequence is adapted from Bodmer's TFT_eSPI 2.5.43,
as distributed with Freenove's display resources. The source file in that
package is identical to TFT_eSPI's upstream TFT_Drivers/ST7796_Init.h.
The TFT_eSPI licence file records MIT/BSD conditions and includes
Copyright (c) 2023 Bodmer. The unchanged upstream notice is retained in
[TFT_eSPI.txt](../firmware/assets/licenses/TFT_eSPI.txt). Keep this notice,
including its applicable copyright, licence conditions and disclaimer, with
source distributions and binary releases containing the adapted initialization
code. For binary releases, include it in the accompanying documentation or
other materials, such as the firmware release archive.

Sources:

- [TFT_eSPI ST7796 initialization](https://github.com/Bodmer/TFT_eSPI/blob/V2.5.43/TFT_Drivers/ST7796_Init.h)
- [TFT_eSPI licence](https://github.com/Bodmer/TFT_eSPI/blob/V2.5.43/license.txt)
- [Freenove display resources](https://github.com/Freenove/Freenove_ESP32_Display)

Freenove's overall resource package has separate CC BY-NC-SA 3.0 terms.
The TFT_eSPI attribution here covers the identified library source, not
permission to reuse other Freenove documentation or resources under MIT.

## Rust dependencies

The direct libraries are log, serde, serde_json, chrono, chrono-tz,
embedded-graphics, zeroize, esp-idf-svc, embedded-hal, mipidsi and anyhow,
with embuild used during compilation. [firmware/Cargo.toml](../firmware/Cargo.toml) defines these
dependencies and [firmware/Cargo.lock](../firmware/Cargo.lock) records their resolved versions.

[third-party-rust-2026-10-04.csv](third-party-rust-2026-10-04.csv) lists the 194 external package versions in
the lockfile, their declared licences, source repositories, package archive
URLs, SHA-256 checksums and licence files included in the archives. This
includes transitive dependencies, host tools and packages for other targets;
it is not a list of components necessarily present in every firmware image.
The `available_license_option` column identifies an available licence path
where upstream offers alternatives; it does not relicense a package.

The declared terms include MIT, Apache-2.0, BSD-3-Clause, ISC and Zlib.
unicode-ident additionally includes Unicode-3.0 terms, whose notice must
be retained for the covered material. regex-syntax also includes separately
licensed Unicode tables whose original notices are retained. Copyright and applicable licence
texts remain required even for packages without a separate licence file
inside the package archive. Retained notices for Chrono, Chrono-TZ, Serde
and serde_json are under [firmware/assets/licenses/](../firmware/assets/licenses/). Chrono-TZ also uses
public-domain IANA time-zone data.

## ESP-IDF and Espressif binary libraries

The firmware targets ESP32 using ESP-IDF v5.5.5 and the esp Rust toolchain.
ESP-IDF's original open source code is under Apache-2.0. Other SDK sources
include FreeRTOS (MIT), lwIP and wpa_supplicant (BSD), TLSF (BSD-3-Clause),
Newlib (component-specific terms) and Mbed TLS (Apache-2.0 or GPL-2.0-or-later,
with Apache-2.0 selected for this distribution).
Individual source notices and upstream licence texts govern each component.

Sources:

- [ESP-IDF v5.5.5](https://github.com/espressif/esp-idf/tree/v5.5.5)
- [ESP-IDF copyrights and licences](https://docs.espressif.com/projects/esp-idf/en/v5.5.5/esp32/COPYRIGHT.html)

[third-party-esp-idf-2026-10-04.json](third-party-esp-idf-2026-10-04.json) records the SDK's upstream submodule
repositories, exact revisions and licence source links. It includes optional
components and other chip targets; inclusion depends on build configuration.

The normal ESP32 WLAN build links precompiled Wi-Fi and PHY libraries whose
complete implementation source is not publicly available. The SDK selects:

Wi-Fi: espressif/esp32-wifi-lib, Apache-2.0,
revision 22bb3517b08760ed43b889013f8a122db0d46da0.

- [esp32-wifi-lib source repository](https://github.com/espressif/esp32-wifi-lib/tree/22bb3517b08760ed43b889013f8a122db0d46da0)

PHY: espressif/esp-phy-lib, Apache-2.0,
revision 59c1234e929212aec0fdda75769b759951235536.

- [esp-phy-lib source repository](https://github.com/espressif/esp-phy-lib/tree/59c1234e929212aec0fdda75769b759951235536)

Configuration-dependent coexistence libraries come from esp-coex-lib under
Apache-2.0, revision 79e618f033e926d134decc6d95bb1b1850bd032c.

- [esp-coex-lib source repository](https://github.com/espressif/esp-coex-lib/tree/79e618f033e926d134decc6d95bb1b1850bd032c)

Publishing the project's open source code does not change these libraries'
source availability. The project's MIT licence permits distribution of the
firmware without requiring disclosure of those libraries' implementation
source. Binary distributions must retain the project's MIT copyright and
permission notice and satisfy each included component's upstream terms,
including applicable licence, copyright and NOTICE requirements. This
declaration does not replace those terms or grant exemptions from them.

## HTTPS certificate data

HTTPS verification uses ESP-IDF's full root CA certificate bundle, derived
from Mozilla certificate data dated 2025-02-25 in the pinned SDK. The
converted Mozilla certificate store is under MPL 2.0. Preserve applicable
notices and provide recipients with access to the MPL-covered data source
when distributing the generated bundle. The data's licence does not replace
the project's own code licence.

Sources:

- [ESP-IDF certificate data](https://github.com/espressif/esp-idf/blob/v5.5.5/components/mbedtls/esp_crt_bundle/cacrt_all.pem)
- [Mozilla CA certificate extraction and licence](https://curl.se/docs/caextract.html)
- [MPL 2.0 distribution guidance](https://www.mozilla.org/en-US/MPL/2.0/FAQ/)

## Weather and location data

Weather forecasts and current conditions come from Open-Meteo. Location
search uses Open-Meteo's geocoding service with location data from GeoNames.
Open-Meteo supplies data under CC BY 4.0. The display selects forecast
entries, rounds temperatures, converts units and maps weather codes to
symbols. Data attribution and identification of modifications accompany
redistribution of the data.

Sources and terms:

- [Open-Meteo](https://open-meteo.com/)
- [GeoNames](https://www.geonames.org/)
- [Open-Meteo data licence](https://open-meteo.com/en/licence)
- [Open-Meteo service terms](https://open-meteo.com/en/terms)

The free public API permits non-commercial service use and imposes request
limits. Commercial service use requires an appropriate arrangement or another
provider. These conditions govern API access; they do not impose a
non-commercial restriction on the project's MIT-licensed source code.

## Build and asset tools

The development workflow uses Rust/Cargo, rustup, espup, ldproxy, CMake,
Ninja, Python, libclang and esptool. Asset conversion uses Pillow 9.0.1,
FreeType 2.11.1, CairoSVG 2.7.1, Cairo 1.16.0 and cairocffi. Generated fonts
and symbols are checked into the repository, so ordinary firmware builds
do not require these asset converters. The tools retain their own upstream
licences; using a separate build, conversion or flashing tool does not
replace the licences of the project's source or assets.

This dated declaration and its inventories identify the dependency versions
and sources recorded here. Applicable upstream copyright, licence and
NOTICE texts remain authoritative and must be retained where required.

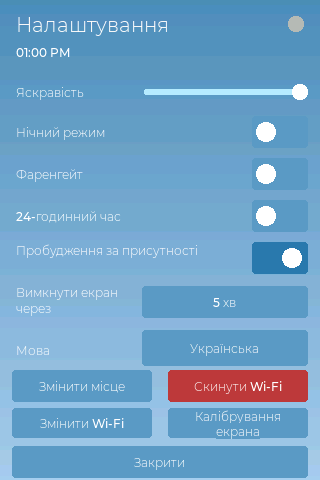
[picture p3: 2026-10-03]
images/settings-uk.png

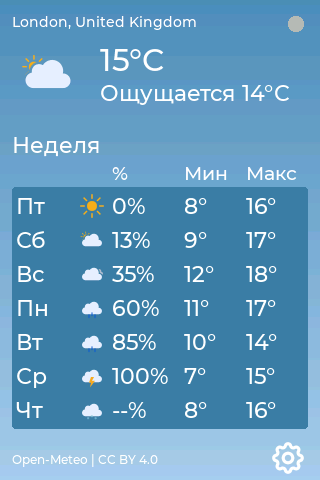
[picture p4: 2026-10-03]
images/weather-week-ru.png

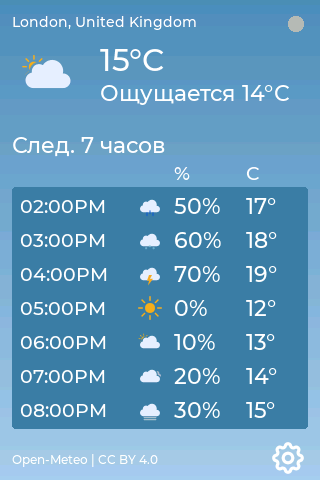
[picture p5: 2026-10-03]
images/weather-hours-ru.png

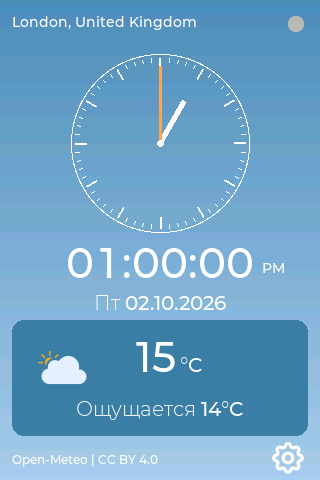
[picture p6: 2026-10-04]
images/weather-clock-ru.png

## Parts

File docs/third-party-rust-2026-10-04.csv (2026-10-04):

package | version | declared_license | available_license_option | sha256 | source_archive | repository | license_files_in_archive
aho-corasick | 1.1.5 | Unlicense OR MIT | MIT | c982642fa9e8606056828ee9a8505737230110bb1099153c79efe865c59d12ba | https://static.crates.io/crates/aho-corasick/aho-corasick-1.1.5.crate | https://github.com/BurntSushi/aho-corasick | aho-corasick-1.1.5/COPYING; aho-corasick-1.1.5/LICENSE-MIT; aho-corasick-1.1.5/UNLICENSE
aligned | 0.4.3 | MIT OR Apache-2.0 | MIT | ee4508988c62edf04abd8d92897fca0c2995d907ce1dfeaf369dac3716a40685 | https://static.crates.io/crates/aligned/aligned-0.4.3.crate | https://github.com/rust-embedded-community/aligned | aligned-0.4.3/LICENSE-APACHE; aligned-0.4.3/LICENSE-MIT
android_system_properties | 0.1.6 | MIT OR Apache-2.0 | MIT | ae221649c9976a6f6c56ae1facf410f3ddb33cc661c4b7b61020a912d4237fbc | https://static.crates.io/crates/android_system_properties/android_system_properties-0.1.6.crate | https://github.com/nical/android_system_properties | android_system_properties-0.1.6/LICENSE-APACHE; android_system_properties-0.1.6/LICENSE-MIT
anyhow | 1.0.104 | MIT OR Apache-2.0 | MIT | 330a5ed07fa54e4702c9d6c4174f74427fc0ef6e214bbd677ae50a5099946470 | https://static.crates.io/crates/anyhow/anyhow-1.0.104.crate | https://github.com/dtolnay/anyhow | anyhow-1.0.104/LICENSE-APACHE; anyhow-1.0.104/LICENSE-MIT
as-slice | 0.2.1 | MIT OR Apache-2.0 | MIT | 516b6b4f0e40d50dcda9365d53964ec74560ad4284da2e7fc97122cd83174516 | https://static.crates.io/crates/as-slice/as-slice-0.2.1.crate | https://github.com/japaric/as-slice | as-slice-0.2.1/LICENSE-APACHE; as-slice-0.2.1/LICENSE-MIT
atomic-waker | 1.1.2 | Apache-2.0 OR MIT | MIT | 1505bd5d3d116872e7271a6d4e16d81d0c8570876c8de68093a09ac269d8aac0 | https://static.crates.io/crates/atomic-waker/atomic-waker-1.1.2.crate | https://github.com/smol-rs/atomic-waker | atomic-waker-1.1.2/LICENSE-APACHE; atomic-waker-1.1.2/LICENSE-MIT; atomic-waker-1.1.2/LICENSE-THIRD-PARTY
autocfg | 1.5.1 | Apache-2.0 OR MIT | MIT | f2032f911046de80f0a198e0901378627c33f59ea0ac00e363d481118bd70a53 | https://static.crates.io/crates/autocfg/autocfg-1.5.1.crate | https://github.com/cuviper/autocfg | autocfg-1.5.1/LICENSE-APACHE; autocfg-1.5.1/LICENSE-MIT
az | 1.2.1 | MIT/Apache-2.0 | MIT | 7b7e4c2464d97fe331d41de9d5db0def0a96f4d823b8b32a2efd503578988973 | https://static.crates.io/crates/az/az-1.2.1.crate | https://gitlab.com/tspiteri/az | az-1.2.1/LICENSE-APACHE; az-1.2.1/LICENSE-MIT
bindgen | 0.71.1 | BSD-3-Clause | BSD-3-Clause | 5f58bf3d7db68cfbac37cfc485a8d711e87e064c3d0fe0435b92f7a407f9d6b3 | https://static.crates.io/crates/bindgen/bindgen-0.71.1.crate | https://github.com/rust-lang/rust-bindgen | bindgen-0.71.1/LICENSE
bitflags | 1.3.2 | MIT/Apache-2.0 | MIT | bef38d45163c2f1dde094a7dfd33ccf595c92905c8f8f4fdc18d06fb1037718a | https://static.crates.io/crates/bitflags/bitflags-1.3.2.crate | https://github.com/bitflags/bitflags | bitflags-1.3.2/LICENSE-APACHE; bitflags-1.3.2/LICENSE-MIT
bitflags | 2.13.2 | MIT OR Apache-2.0 | MIT | 3ded4057c258ba199e2d26386d3af3780957ecaee6c4ef4041c6b4b8b97c0b06 | https://static.crates.io/crates/bitflags/bitflags-2.13.2.crate | https://github.com/bitflags/bitflags | bitflags-2.13.2/LICENSE-APACHE; bitflags-2.13.2/LICENSE-MIT
bstr | 1.13.1 | MIT OR Apache-2.0 | MIT | 6bb31b46c14244e20ee9984b11bf5c992b91fb6939fea616e3512c8baecdbe5f | https://static.crates.io/crates/bstr/bstr-1.13.1.crate | https://github.com/BurntSushi/bstr | bstr-1.13.1/COPYING; bstr-1.13.1/LICENSE-APACHE; bstr-1.13.1/LICENSE-MIT
build-time | 0.1.3 | MIT | MIT | f1219c19fc29b7bfd74b7968b420aff5bc951cf517800176e795d6b2300dd382 | https://static.crates.io/crates/build-time/build-time-0.1.3.crate | https://github.com/AlephAlpha/build-time
bumpalo | 3.20.3 | MIT OR Apache-2.0 | MIT | 72f5acc6cb2ba439de613abc23857ec3d78374d8ed5ac84e9d11336e87da8649 | https://static.crates.io/crates/bumpalo/bumpalo-3.20.3.crate | https://github.com/fitzgen/bumpalo | bumpalo-3.20.3/LICENSE-APACHE; bumpalo-3.20.3/LICENSE-MIT
byteorder | 1.5.0 | Unlicense OR MIT | MIT | 1fd0f2584146f6f2ef48085050886acf353beff7305ebd1ae69500e27c67f64b | https://static.crates.io/crates/byteorder/byteorder-1.5.0.crate | https://github.com/BurntSushi/byteorder | byteorder-1.5.0/COPYING; byteorder-1.5.0/LICENSE-MIT; byteorder-1.5.0/UNLICENSE
camino | 1.2.6 | MIT OR Apache-2.0 | MIT | bbbad30e4b4c14a39e3cc8aed085a12a327257c316619c93581e017bc52be591 | https://static.crates.io/crates/camino/camino-1.2.6.crate | https://github.com/camino-rs/camino | camino-1.2.6/LICENSE-APACHE; camino-1.2.6/LICENSE-MIT
cargo-platform | 0.1.9 | MIT OR Apache-2.0 | MIT | e35af189006b9c0f00a064685c727031e3ed2d8020f7ba284d78cc2671bd36ea | https://static.crates.io/crates/cargo-platform/cargo-platform-0.1.9.crate | https://github.com/rust-lang/cargo | cargo-platform-0.1.9/LICENSE-APACHE; cargo-platform-0.1.9/LICENSE-MIT
cargo_metadata | 0.18.1 | MIT | MIT | 2d886547e41f740c616ae73108f6eb70afe6d940c7bc697cb30f13daec073037 | https://static.crates.io/crates/cargo_metadata/cargo_metadata-0.18.1.crate | https://github.com/oli-obk/cargo_metadata | cargo_metadata-0.18.1/LICENSE-MIT
cc | 1.5.1 | MIT OR Apache-2.0 | MIT | f360145194ee8e21db5ee7f3fcd4fe52210864c75c985dae33218202c8bbe040 | https://static.crates.io/crates/cc/cc-1.5.1.crate | https://github.com/rust-lang/cc-rs | cc-1.5.1/LICENSE-APACHE; cc-1.5.1/LICENSE-MIT
cexpr | 0.6.0 | Apache-2.0/MIT | MIT | 6fac387a98bb7c37292057cffc56d62ecb629900026402633ae9160df93a8766 | https://static.crates.io/crates/cexpr/cexpr-0.6.0.crate | https://github.com/jethrogb/rust-cexpr | cexpr-0.6.0/LICENSE-APACHE; cexpr-0.6.0/LICENSE-MIT
cfg-if | 1.0.5 | MIT OR Apache-2.0 | MIT | 4e7648175b45a9a48536d676f68d918270699102aa8dab5496df06904c914600 | https://static.crates.io/crates/cfg-if/cfg-if-1.0.5.crate | https://github.com/rust-lang/cfg-if | cfg-if-1.0.5/LICENSE-APACHE; cfg-if-1.0.5/LICENSE-MIT
cfg_aliases | 0.2.2 | MIT | MIT | f079e83a288787bcd14a6aea84cee5c87a67c5a3e660c30f557a3d24761b3527 | https://static.crates.io/crates/cfg_aliases/cfg_aliases-0.2.2.crate | https://github.com/katharostech/cfg_aliases | cfg_aliases-0.2.2/LICENSE; cfg_aliases-0.2.2/NOTICES.md
chrono | 0.4.45 | MIT OR Apache-2.0 | MIT | 1aa79e62e7697b8e29b513a68abacf485adcd1fe8284a4316c5ae868e6633327 | https://static.crates.io/crates/chrono/chrono-0.4.45.crate | https://github.com/chronotope/chrono | chrono-0.4.45/LICENSE.txt
chrono-tz | 0.10.4 | MIT OR Apache-2.0 | MIT | a6139a8597ed92cf816dfb33f5dd6cf0bb93a6adc938f11039f371bc5bcd26c3 | https://static.crates.io/crates/chrono-tz/chrono-tz-0.10.4.crate | https://github.com/chronotope/chrono-tz | chrono-tz-0.10.4/LICENSE; chrono-tz-0.10.4/tz/LICENSE
clang-sys | 1.9.1 | Apache-2.0 | Apache-2.0 | 157a8ba7b480713b56f4c09fd13fc3e0a22a5dfab8097ba61cbc5feef950788a | https://static.crates.io/crates/clang-sys/clang-sys-1.9.1.crate | https://github.com/KyleMayes/clang-sys | clang-sys-1.9.1/LICENSE.txt
cmake | 0.1.58 | MIT OR Apache-2.0 | MIT | c0f78a02292a74a88ac736019ab962ece0bc380e3f977bf72e376c5d78ff0678 | https://static.crates.io/crates/cmake/cmake-0.1.58.crate | https://github.com/rust-lang/cmake-rs | cmake-0.1.58/LICENSE-APACHE; cmake-0.1.58/LICENSE-MIT
compile-fmt | 0.1.0 | MIT OR Apache-2.0 | MIT | bed69047ed42e52c7e38d6421eeb8ceefb4f2a2b52eed59137f7bad7908f6800 | https://static.crates.io/crates/compile-fmt/compile-fmt-0.1.0.crate | https://github.com/slowli/compile-fmt | compile-fmt-0.1.0/LICENSE-APACHE; compile-fmt-0.1.0/LICENSE-MIT
const_format | 0.2.36 | Zlib | Zlib | 4481a617ad9a412be3b97c5d403fef8ed023103368908b9c50af598ff467cc1e | https://static.crates.io/crates/const_format/const_format-0.2.36.crate | https://github.com/rodrimati1992/const_format_crates/ | const_format-0.2.36/LICENSE-ZLIB.md
const_format_proc_macros | 0.2.34 | Zlib | Zlib | 1d57c2eccfb16dbac1f4e61e206105db5820c9d26c3c472bc17c774259ef7744 | https://static.crates.io/crates/const_format_proc_macros/const_format_proc_macros-0.2.34.crate | https://github.com/rodrimati1992/const_format_crates/ | const_format_proc_macros-0.2.34/LICENSE-ZLIB.md
core-foundation-sys | 0.8.7 | MIT OR Apache-2.0 | MIT | 773648b94d0e5d620f64f280777445740e61fe701025087ec8b57f45c791888b | https://static.crates.io/crates/core-foundation-sys/core-foundation-sys-0.8.7.crate | https://github.com/servo/core-foundation-rs | core-foundation-sys-0.8.7/LICENSE-APACHE; core-foundation-sys-0.8.7/LICENSE-MIT
critical-section | 1.2.0 | MIT OR Apache-2.0 | MIT | 790eea4361631c5e7d22598ecd5723ff611904e3344ce8720784c93e3d83d40b | https://static.crates.io/crates/critical-section/critical-section-1.2.0.crate | https://github.com/rust-embedded/critical-section | critical-section-1.2.0/LICENSE-APACHE; critical-section-1.2.0/LICENSE-MIT
crossbeam-deque | 0.8.8 | MIT OR Apache-2.0 | MIT | 622f3fc73690be383c7214310406f28a90e6edeadc3cea882f9d71e495b9711a | https://static.crates.io/crates/crossbeam-deque/crossbeam-deque-0.8.8.crate | https://github.com/crossbeam-rs/crossbeam | crossbeam-deque-0.8.8/LICENSE-APACHE; crossbeam-deque-0.8.8/LICENSE-MIT
crossbeam-epoch | 0.9.21 | MIT OR Apache-2.0 | MIT | dc74980687109a3b14c72fd458107bf0baa1da1a1a805e178d15501ba9b86d9d | https://static.crates.io/crates/crossbeam-epoch/crossbeam-epoch-0.9.21.crate | https://github.com/crossbeam-rs/crossbeam | crossbeam-epoch-0.9.21/LICENSE-APACHE; crossbeam-epoch-0.9.21/LICENSE-MIT
crossbeam-utils | 0.8.23 | MIT OR Apache-2.0 | MIT | a31eee39dddec8330830986fcd7625edb5a24ec90ea038215273bbc3adb08ac6 | https://static.crates.io/crates/crossbeam-utils/crossbeam-utils-0.8.23.crate | https://github.com/crossbeam-rs/crossbeam | crossbeam-utils-0.8.23/LICENSE-APACHE; crossbeam-utils-0.8.23/LICENSE-MIT
cvt | 0.1.2 | Apache-2.0 | Apache-2.0 | d2ae9bf77fbf2d39ef573205d554d87e86c12f1994e9ea335b0651b9b278bcf1 | https://static.crates.io/crates/cvt/cvt-0.1.2.crate | https://github.com/marmistrz/cvt | cvt-0.1.2/LICENSE
darling | 0.21.3 | MIT | MIT | 9cdf337090841a411e2a7f3deb9187445851f91b309c0c0a29e05f74a00a48c0 | https://static.crates.io/crates/darling/darling-0.21.3.crate | https://github.com/TedDriggs/darling | darling-0.21.3/LICENSE
darling_core | 0.21.3 | MIT | MIT | 1247195ecd7e3c85f83c8d2a366e4210d588e802133e1e355180a9870b517ea4 | https://static.crates.io/crates/darling_core/darling_core-0.21.3.crate | https://github.com/TedDriggs/darling | darling_core-0.21.3/LICENSE
darling_macro | 0.21.3 | MIT | MIT | d38308df82d1080de0afee5d069fa14b0326a88c14f15c5ccda35b4a6c414c81 | https://static.crates.io/crates/darling_macro/darling_macro-0.21.3.crate | https://github.com/TedDriggs/darling | darling_macro-0.21.3/LICENSE
defmt | 1.1.1 | MIT OR Apache-2.0 | MIT | e2953bfe4f93bbd20cc71198842756f77d161884c99ebbabc41d80231ded88d1 | https://static.crates.io/crates/defmt/defmt-1.1.1.crate | https://github.com/knurling-rs/defmt | defmt-1.1.1/LICENSE-APACHE; defmt-1.1.1/LICENSE-MIT
defmt-macros | 1.1.1 | MIT OR Apache-2.0 | MIT | bad9c72e7ca2137e0dc3813245a0d282fd6daad32fd800af018306a9169b5fe8 | https://static.crates.io/crates/defmt-macros/defmt-macros-1.1.1.crate | https://github.com/knurling-rs/defmt | defmt-macros-1.1.1/LICENSE-APACHE; defmt-macros-1.1.1/LICENSE-MIT
defmt-parser | 1.0.0 | MIT OR Apache-2.0 | MIT | 10d60334b3b2e7c9d91ef8150abfb6fa4c1c39ebbcf4a81c2e346aad939fee3e | https://static.crates.io/crates/defmt-parser/defmt-parser-1.0.0.crate | https://github.com/knurling-rs/defmt
either | 1.18.0 | MIT OR Apache-2.0 | MIT | 252afb9ae5eaa683babdc6a068b3f5726eb19e05070c731f9b2a23a7c3e8ed34 | https://static.crates.io/crates/either/either-1.18.0.crate | https://github.com/rayon-rs/either | either-1.18.0/LICENSE-APACHE; either-1.18.0/LICENSE-MIT
embassy-futures | 0.1.2 | MIT OR Apache-2.0 | MIT | dc2d050bdc5c21e0862a89256ed8029ae6c290a93aecefc73084b3002cdebb01 | https://static.crates.io/crates/embassy-futures/embassy-futures-0.1.2.crate | https://github.com/embassy-rs/embassy
embassy-sync | 0.8.0 | MIT OR Apache-2.0 | MIT | 7bbd85cf5a5ae56bdf26f618364af642d1d0a4e245cdd75cd9aabda382f65a81 | https://static.crates.io/crates/embassy-sync/embassy-sync-0.8.0.crate | https://github.com/embassy-rs/embassy
embedded-can | 0.4.1 | MIT OR Apache-2.0 | MIT | e9d2e857f87ac832df68fa498d18ddc679175cf3d2e4aa893988e5601baf9438 | https://static.crates.io/crates/embedded-can/embedded-can-0.4.1.crate | https://github.com/rust-embedded/embedded-hal | embedded-can-0.4.1/LICENSE-APACHE; embedded-can-0.4.1/LICENSE-MIT
embedded-graphics | 0.8.2 | MIT OR Apache-2.0 | MIT | 4e8da660bb0c829b34a56a965490597f82a55e767b91f9543be80ce8ccb416fe | https://static.crates.io/crates/embedded-graphics/embedded-graphics-0.8.2.crate | https://github.com/embedded-graphics/embedded-graphics | embedded-graphics-0.8.2/LICENSE-APACHE; embedded-graphics-0.8.2/LICENSE-MIT
embedded-graphics-core | 0.4.1 | MIT OR Apache-2.0 | MIT | 95743bef3ff70fcba3930246c4e6872882bbea0dcc6da2ca860112e0cd4bd09f | https://static.crates.io/crates/embedded-graphics-core/embedded-graphics-core-0.4.1.crate | https://github.com/embedded-graphics/embedded-graphics
embedded-hal | 0.2.7 | MIT OR Apache-2.0 | MIT | 35949884794ad573cf46071e41c9b60efb0cb311e3ca01f7af807af1debc66ff | https://static.crates.io/crates/embedded-hal/embedded-hal-0.2.7.crate | https://github.com/rust-embedded/embedded-hal | embedded-hal-0.2.7/LICENSE-APACHE; embedded-hal-0.2.7/LICENSE-MIT
embedded-hal | 1.0.0 | MIT OR Apache-2.0 | MIT | 361a90feb7004eca4019fb28352a9465666b24f840f5c3cddf0ff13920590b89 | https://static.crates.io/crates/embedded-hal/embedded-hal-1.0.0.crate | https://github.com/rust-embedded/embedded-hal | embedded-hal-1.0.0/LICENSE-APACHE; embedded-hal-1.0.0/LICENSE-MIT
embedded-hal-async | 1.0.0 | MIT OR Apache-2.0 | MIT | 0c4c685bbef7fe13c3c6dd4da26841ed3980ef33e841cddfa15ce8a8fb3f1884 | https://static.crates.io/crates/embedded-hal-async/embedded-hal-async-1.0.0.crate | https://github.com/rust-embedded/embedded-hal | embedded-hal-async-1.0.0/LICENSE-APACHE; embedded-hal-async-1.0.0/LICENSE-MIT
embedded-hal-nb | 1.0.0 | MIT OR Apache-2.0 | MIT | fba4268c14288c828995299e59b12babdbe170f6c6d73731af1b4648142e8605 | https://static.crates.io/crates/embedded-hal-nb/embedded-hal-nb-1.0.0.crate | https://github.com/rust-embedded/embedded-hal | embedded-hal-nb-1.0.0/LICENSE-APACHE; embedded-hal-nb-1.0.0/LICENSE-MIT
embedded-io | 0.7.1 | MIT OR Apache-2.0 | MIT | 9eb1aa714776b75c7e67e1da744b81a129b3ff919c8712b5e1b32252c1f07cc7 | https://static.crates.io/crates/embedded-io/embedded-io-0.7.1.crate | https://github.com/rust-embedded/embedded-hal | embedded-io-0.7.1/LICENSE-APACHE; embedded-io-0.7.1/LICENSE-MIT
embedded-io-async | 0.7.0 | MIT OR Apache-2.0 | MIT | 2564b9f813c544241430e147d8bc454815ef9ac998878d30cc3055449f7fd4c0 | https://static.crates.io/crates/embedded-io-async/embedded-io-async-0.7.0.crate | https://github.com/rust-embedded/embedded-hal | embedded-io-async-0.7.0/LICENSE-APACHE; embedded-io-async-0.7.0/LICENSE-MIT
embedded-svc | 0.29.0 | MIT OR Apache-2.0 | MIT | 8bfc6d05bac4af70b0795d1f1b6ddd44aa85ad04b05d34d64b1b9fce36de107e | https://static.crates.io/crates/embedded-svc/embedded-svc-0.29.0.crate | https://github.com/esp-rs/embedded-svc | embedded-svc-0.29.0/LICENSE-APACHE; embedded-svc-0.29.0/LICENSE-MIT
embuild | 0.33.5 | MIT OR Apache-2.0 | MIT | 2c41359cdde377dfd2e8aa34c09f9798a3ff9b6e4a9de81167c32d6b289521ed | https://static.crates.io/crates/embuild/embuild-0.33.5.crate | https://github.com/esp-rs/embuild | embuild-0.33.5/LICENSE-APACHE; embuild-0.33.5/LICENSE-MIT
enumset | 1.1.14 | MIT/Apache-2.0 | MIT | ccc5801fd11762e24d1e420d01d2ac518f2a2ca4329d4fbb6639f2412b6204e0 | https://static.crates.io/crates/enumset/enumset-1.1.14.crate | https://github.com/Lymia/enumset | enumset-1.1.14/LICENSE-APACHE; enumset-1.1.14/LICENSE-MIT
enumset_derive | 0.15.0 | MIT/Apache-2.0 | MIT | 4bd536557b58c682b217b8fb199afdff47cd3eff260623f19e77074eb073d63a | https://static.crates.io/crates/enumset_derive/enumset_derive-0.15.0.crate | https://github.com/Lymia/enumset | enumset_derive-0.15.0/LICENSE-APACHE; enumset_derive-0.15.0/LICENSE-MIT
envy | 0.4.2 | MIT | MIT | 3f47e0157f2cb54f5ae1bd371b30a2ae4311e1c028f575cd4e81de7353215965 | https://static.crates.io/crates/envy/envy-0.4.2.crate | https://github.com/softprops/envy | envy-0.4.2/LICENSE
equivalent | 1.0.2 | Apache-2.0 OR MIT | MIT | 877a4ace8713b0bcf2a4e7eec82529c029f1d0619886d18145fea96c3ffe5c0f | https://static.crates.io/crates/equivalent/equivalent-1.0.2.crate | https://github.com/indexmap-rs/equivalent | equivalent-1.0.2/LICENSE-APACHE; equivalent-1.0.2/LICENSE-MIT
errno | 0.3.14 | MIT OR Apache-2.0 | MIT | 39cab71617ae0d63f51a36d69f866391735b51691dbda63cf6f96d042b63efeb | https://static.crates.io/crates/errno/errno-0.3.14.crate | https://github.com/lambda-fairy/rust-errno | errno-0.3.14/LICENSE-APACHE; errno-0.3.14/LICENSE-MIT
esp-idf-hal | 0.47.0 | MIT OR Apache-2.0 | MIT | 52353908ed84c0290500557d7097ebf95985a6a9c98ea89cfb1ff9606ff7608f | https://static.crates.io/crates/esp-idf-hal/esp-idf-hal-0.47.0.crate | https://github.com/esp-rs/esp-idf-hal | esp-idf-hal-0.47.0/LICENSE-APACHE; esp-idf-hal-0.47.0/LICENSE-MIT
esp-idf-svc | 0.53.0 | MIT OR Apache-2.0 | MIT | 80528df10e8ee316043f0a53bcbec3126a217168813afdcae11078a5f34e60c9 | https://static.crates.io/crates/esp-idf-svc/esp-idf-svc-0.53.0.crate | https://github.com/esp-rs/esp-idf-svc | esp-idf-svc-0.53.0/LICENSE-APACHE; esp-idf-svc-0.53.0/LICENSE-MIT
esp-idf-sys | 0.38.1 | MIT OR Apache-2.0 | MIT | 77deab475cab0b375e20c7450b0d265f928480af712214c84e848df0f57c29f4 | https://static.crates.io/crates/esp-idf-sys/esp-idf-sys-0.38.1.crate | https://github.com/esp-rs/esp-idf-sys | esp-idf-sys-0.38.1/LICENSE-APACHE; esp-idf-sys-0.38.1/LICENSE-MIT
fastrand | 2.5.0 | Apache-2.0 OR MIT | MIT | da7c62ceae207dd37ea5b845da6a0696c799f85e97da1ab5b7910be3c1c80223 | https://static.crates.io/crates/fastrand/fastrand-2.5.0.crate | https://github.com/smol-rs/fastrand | fastrand-2.5.0/LICENSE-APACHE; fastrand-2.5.0/LICENSE-MIT
filetime | 0.2.29 | MIT/Apache-2.0 | MIT | 5c287a33c7f0a620c38e641e7f60827713987b3c0f26e8ddc9462cc69cf75759 | https://static.crates.io/crates/filetime/filetime-0.2.29.crate | https://github.com/alexcrichton/filetime | filetime-0.2.29/LICENSE-APACHE; filetime-0.2.29/LICENSE-MIT
find-msvc-tools | 0.1.14 | MIT OR Apache-2.0 | MIT | aedcfb3409746eddb02b9e19ebda1c3394f759a152e48ee875a0844d1b955484 | https://static.crates.io/crates/find-msvc-tools/find-msvc-tools-0.1.14.crate | https://github.com/rust-lang/cc-rs | find-msvc-tools-0.1.14/LICENSE-APACHE; find-msvc-tools-0.1.14/LICENSE-MIT
float-cmp | 0.9.0 | MIT | MIT | 98de4bbd547a563b716d8dfa9aad1cb19bfab00f4fa09a6a4ed21dbcf44ce9c4 | https://static.crates.io/crates/float-cmp/float-cmp-0.9.0.crate | https://github.com/mikedilger/float-cmp | float-cmp-0.9.0/LICENSE
fnv | 1.0.7 | Apache-2.0 / MIT | MIT | 3f9eec918d3f24069decb9af1554cad7c880e2da24a9afd88aca000531ab82c1 | https://static.crates.io/crates/fnv/fnv-1.0.7.crate | https://github.com/servo/rust-fnv | fnv-1.0.7/LICENSE-APACHE; fnv-1.0.7/LICENSE-MIT
fs_at | 0.2.1 | Apache-2.0 | Apache-2.0 | 14af6c9694ea25db25baa2a1788703b9e7c6648dcaeeebeb98f7561b5384c036 | https://static.crates.io/crates/fs_at/fs_at-0.2.1.crate | https://github.com/rbtcollins/fs_at.git
futures-core | 0.3.34 | MIT OR Apache-2.0 | MIT | 92d699e522242e69e3003b94ecc1f960f3a5e015aa7c5d7486e65ad01dd94f5e | https://static.crates.io/crates/futures-core/futures-core-0.3.34.crate | https://github.com/rust-lang/futures-rs | futures-core-0.3.34/LICENSE-APACHE; futures-core-0.3.34/LICENSE-MIT
futures-io | 0.3.34 | MIT OR Apache-2.0 | MIT | 53c0fa8157de1303bfffdaa1cc2a673bfffb60102f76b0ef4441659124373fed | https://static.crates.io/crates/futures-io/futures-io-0.3.34.crate | https://github.com/rust-lang/futures-rs | futures-io-0.3.34/LICENSE-APACHE; futures-io-0.3.34/LICENSE-MIT
futures-sink | 0.3.34 | MIT OR Apache-2.0 | MIT | 1944426bf7d03f1d14f708785e4b33efd750b36d48a157b836b3efc15ede8e1d | https://static.crates.io/crates/futures-sink/futures-sink-0.3.34.crate | https://github.com/rust-lang/futures-rs | futures-sink-0.3.34/LICENSE-APACHE; futures-sink-0.3.34/LICENSE-MIT
futures-task | 0.3.34 | MIT OR Apache-2.0 | MIT | cd417de3d1d015fc3bfd2b1ea46dfc7bab72ef86f1cc7cc9c78e728b34a6d1fd | https://static.crates.io/crates/futures-task/futures-task-0.3.34.crate | https://github.com/rust-lang/futures-rs | futures-task-0.3.34/LICENSE-APACHE; futures-task-0.3.34/LICENSE-MIT
futures-util | 0.3.34 | MIT OR Apache-2.0 | MIT | 0d50a92467f8ba5dd6e3ee5d4bd04d73ab2e4e1c44474a0674821dfce14b79bc | https://static.crates.io/crates/futures-util/futures-util-0.3.34.crate | https://github.com/rust-lang/futures-rs | futures-util-0.3.34/LICENSE-APACHE; futures-util-0.3.34/LICENSE-MIT
getrandom | 0.4.3 | MIT OR Apache-2.0 | MIT | 300e883d756b2e4ec94e02791f39b04b522276138852cfc41d9fb7e904106099 | https://static.crates.io/crates/getrandom/getrandom-0.4.3.crate | https://github.com/rust-random/getrandom | getrandom-0.4.3/LICENSE-APACHE; getrandom-0.4.3/LICENSE-MIT
glob | 0.3.4 | MIT OR Apache-2.0 | MIT | e4eba85ea1d0a966a983acd07deee566e67395d2d96b6fb39e62b5a833f1eb0b | https://static.crates.io/crates/glob/glob-0.3.4.crate | https://github.com/rust-lang/glob | glob-0.3.4/LICENSE-APACHE; glob-0.3.4/LICENSE-MIT
globset | 0.4.20 | Unlicense OR MIT | MIT | 07c34a9410465b45bd9787443bc7370f37735bad04b0f0cd57ff1a3186c98988 | https://static.crates.io/crates/globset/globset-0.4.20.crate | https://github.com/BurntSushi/ripgrep/tree/master/crates/globset | globset-0.4.20/COPYING; globset-0.4.20/LICENSE-MIT; globset-0.4.20/UNLICENSE
globwalk | 0.8.1 | MIT | MIT | 93e3af942408868f6934a7b85134a3230832b9977cf66125df2f9edcfce4ddcc | https://static.crates.io/crates/globwalk/globwalk-0.8.1.crate | https://github.com/gilnaa/globwalk | globwalk-0.8.1/LICENSE
hash32 | 0.3.1 | MIT OR Apache-2.0 | MIT | 47d60b12902ba28e2730cd37e95b8c9223af2808df9e902d4df49588d1470606 | https://static.crates.io/crates/hash32/hash32-0.3.1.crate | https://github.com/japaric/hash32 | hash32-0.3.1/LICENSE-APACHE; hash32-0.3.1/LICENSE-MIT
hashbrown | 0.17.1 | MIT OR Apache-2.0 | MIT | ed5909b6e89a2db4456e54cd5f673791d7eca6732202bbf2a9cc504fe2f9b84a | https://static.crates.io/crates/hashbrown/hashbrown-0.17.1.crate | https://github.com/rust-lang/hashbrown | hashbrown-0.17.1/LICENSE-APACHE; hashbrown-0.17.1/LICENSE-MIT
heapless | 0.8.0 | MIT OR Apache-2.0 | MIT | 0bfb9eb618601c89945a70e254898da93b13be0388091d42117462b265bb3fad | https://static.crates.io/crates/heapless/heapless-0.8.0.crate | https://github.com/rust-embedded/heapless | heapless-0.8.0/LICENSE-APACHE; heapless-0.8.0/LICENSE-MIT
heapless | 0.9.3 | MIT OR Apache-2.0 | MIT | 25ba4bd83f9415b58b4ed8dc5714c76e626a105be4646c02630ad730ad3b5aa4 | https://static.crates.io/crates/heapless/heapless-0.9.3.crate | https://github.com/rust-embedded/heapless | heapless-0.9.3/LICENSE-APACHE; heapless-0.9.3/LICENSE-MIT
heck | 0.4.1 | MIT OR Apache-2.0 | MIT | 95505c38b4572b2d910cecb0281560f54b440a19336cbbcb27bf6ce6adc6f5a8 | https://static.crates.io/crates/heck/heck-0.4.1.crate | https://github.com/withoutboats/heck | heck-0.4.1/LICENSE-APACHE; heck-0.4.1/LICENSE-MIT
heck | 0.5.0 | MIT OR Apache-2.0 | MIT | 2304e00983f87ffb38b55b444b5e3b60a884b5d30c0fca7d82fe33449bbe55ea | https://static.crates.io/crates/heck/heck-0.5.0.crate | https://github.com/withoutboats/heck | heck-0.5.0/LICENSE-APACHE; heck-0.5.0/LICENSE-MIT
home | 0.5.12 | MIT OR Apache-2.0 | MIT | cc627f471c528ff0c4a49e1d5e60450c8f6461dd6d10ba9dcd3a61d3dff7728d | https://static.crates.io/crates/home/home-0.5.12.crate | https://github.com/rust-lang/cargo | home-0.5.12/LICENSE-APACHE; home-0.5.12/LICENSE-MIT
iana-time-zone | 0.1.65 | MIT OR Apache-2.0 | MIT | e31bc9ad994ba00e440a8aa5c9ef0ec67d5cb5e5cb0cc7f8b744a35b389cc470 | https://static.crates.io/crates/iana-time-zone/iana-time-zone-0.1.65.crate | https://github.com/strawlab/iana-time-zone | iana-time-zone-0.1.65/LICENSE-APACHE; iana-time-zone-0.1.65/LICENSE-MIT
iana-time-zone-haiku | 0.1.2 | MIT OR Apache-2.0 | MIT | f31827a206f56af32e590ba56d5d2d085f558508192593743f16b2306495269f | https://static.crates.io/crates/iana-time-zone-haiku/iana-time-zone-haiku-0.1.2.crate | https://github.com/strawlab/iana-time-zone | iana-time-zone-haiku-0.1.2/LICENSE-APACHE; iana-time-zone-haiku-0.1.2/LICENSE-MIT
ident_case | 1.0.1 | MIT/Apache-2.0 | MIT | b9e0384b61958566e926dc50660321d12159025e767c18e043daf26b70104c39 | https://static.crates.io/crates/ident_case/ident_case-1.0.1.crate | https://github.com/TedDriggs/ident_case | ident_case-1.0.1/LICENSE
ignore | 0.4.33 | Unlicense OR MIT | MIT | 00b69833ed729dc5aa7d19541d96d6cf8e9137194207a04916d658e43168402f | https://static.crates.io/crates/ignore/ignore-0.4.33.crate | https://github.com/BurntSushi/ripgrep/tree/master/crates/ignore | ignore-0.4.33/COPYING; ignore-0.4.33/LICENSE-MIT; ignore-0.4.33/UNLICENSE
indexmap | 2.14.2 | Apache-2.0 OR MIT | MIT | cc4e190f5d26ca7051642629da2c52fc03bde85a03197c99408dcd291734c855 | https://static.crates.io/crates/indexmap/indexmap-2.14.2.crate | https://github.com/indexmap-rs/indexmap | indexmap-2.14.2/LICENSE-APACHE; indexmap-2.14.2/LICENSE-MIT
itertools | 0.13.0 | MIT OR Apache-2.0 | MIT | 413ee7dfc52ee1a4949ceeb7dbc8a33f2d6c088194d9f922fb8318faf1f01186 | https://static.crates.io/crates/itertools/itertools-0.13.0.crate | https://github.com/rust-itertools/itertools | itertools-0.13.0/LICENSE-APACHE; itertools-0.13.0/LICENSE-MIT
itoa | 1.0.18 | MIT OR Apache-2.0 | MIT | 8f42a60cbdf9a97f5d2305f08a87dc4e09308d1276d28c869c684d7777685682 | https://static.crates.io/crates/itoa/itoa-1.0.18.crate | https://github.com/dtolnay/itoa | itoa-1.0.18/LICENSE-APACHE; itoa-1.0.18/LICENSE-MIT
js-sys | 0.3.106 | MIT OR Apache-2.0 | MIT | 7883d941dae510fb2d978fc3fe018c71c9e2892fd38854de3e8b92c2e5ad9cc5 | https://static.crates.io/crates/js-sys/js-sys-0.3.106.crate | https://github.com/wasm-bindgen/wasm-bindgen/tree/master/crates/js-sys | js-sys-0.3.106/LICENSE-APACHE; js-sys-0.3.106/LICENSE-MIT
konst | 0.2.20 | Zlib | Zlib | 128133ed7824fcd73d6e7b17957c5eb7bacb885649bd8c69708b2331a10bcefb | https://static.crates.io/crates/konst/konst-0.2.20.crate | https://github.com/rodrimati1992/konst/ | konst-0.2.20/LICENSE-ZLIB.md
konst_macro_rules | 0.2.19 | Zlib | Zlib | a4933f3f57a8e9d9da04db23fb153356ecaf00cbd14aee46279c33dc80925c37 | https://static.crates.io/crates/konst_macro_rules/konst_macro_rules-0.2.19.crate | https://github.com/rodrimati1992/konst/ | konst_macro_rules-0.2.19/LICENSE-ZLIB.md
libc | 0.2.189 | MIT OR Apache-2.0 | MIT | 3eaf3ede3fee6db1a4c2ee091bf8a8b4dccdc6d17f656fb07896ee72867612f2 | https://static.crates.io/crates/libc/libc-0.2.189.crate | https://github.com/rust-lang/libc | libc-0.2.189/LICENSE-APACHE; libc-0.2.189/LICENSE-MIT
libloading | 0.8.9 | ISC | ISC | d7c4b02199fee7c5d21a5ae7d8cfa79a6ef5bb2fc834d6e9058e89c825efdc55 | https://static.crates.io/crates/libloading/libloading-0.8.9.crate | https://github.com/nagisa/rust_libloading/ | libloading-0.8.9/LICENSE
linux-raw-sys | 0.12.1 | Apache-2.0 WITH LLVM-exception OR Apache-2.0 OR MIT | MIT | 32a66949e030da00e8c7d4434b251670a91556f4144941d37452769c25d58a53 | https://static.crates.io/crates/linux-raw-sys/linux-raw-sys-0.12.1.crate | https://github.com/sunfishcode/linux-raw-sys | linux-raw-sys-0.12.1/COPYRIGHT; linux-raw-sys-0.12.1/LICENSE-APACHE; linux-raw-sys-0.12.1/LICENSE-Apache-2.0_WITH_LLVM-exception; linux-raw-sys-0.12.1/LICENSE-MIT
linux-raw-sys | 0.4.15 | Apache-2.0 WITH LLVM-exception OR Apache-2.0 OR MIT | MIT | d26c52dbd32dccf2d10cac7725f8eae5296885fb5703b261f7d0a0739ec807ab | https://static.crates.io/crates/linux-raw-sys/linux-raw-sys-0.4.15.crate | https://github.com/sunfishcode/linux-raw-sys | linux-raw-sys-0.4.15/COPYRIGHT; linux-raw-sys-0.4.15/LICENSE-APACHE; linux-raw-sys-0.4.15/LICENSE-Apache-2.0_WITH_LLVM-exception; linux-raw-sys-0.4.15/LICENSE-MIT
log | 0.4.34 | MIT OR Apache-2.0 | MIT | f9f8bd3e56ce4dfc153cf470fffbfa98c7620958b312ca5c3a4b8d5181fd13c6 | https://static.crates.io/crates/log/log-0.4.34.crate | https://github.com/rust-lang/log | log-0.4.34/LICENSE-APACHE; log-0.4.34/LICENSE-MIT
memchr | 2.8.3 | Unlicense OR MIT | MIT | cf8baf1c55e62ffcace7a9f06f4bd9cd3f0c4beb022d3b367256b91b87513d98 | https://static.crates.io/crates/memchr/memchr-2.8.3.crate | https://github.com/BurntSushi/memchr | memchr-2.8.3/COPYING; memchr-2.8.3/LICENSE-MIT; memchr-2.8.3/UNLICENSE
micromath | 2.1.0 | Apache-2.0 OR MIT | MIT | c3c8dda44ff03a2f238717214da50f65d5a53b45cd213a7370424ffdb6fae815 | https://static.crates.io/crates/micromath/micromath-2.1.0.crate | https://github.com/tarcieri/micromath | micromath-2.1.0/LICENSE-APACHE; micromath-2.1.0/LICENSE-MIT
minimal-lexical | 0.2.1 | MIT/Apache-2.0 | MIT | 68354c5c6bd36d73ff3feceb05efa59b6acb7626617f4962be322a825e61f79a | https://static.crates.io/crates/minimal-lexical/minimal-lexical-0.2.1.crate | https://github.com/Alexhuszagh/minimal-lexical | minimal-lexical-0.2.1/LICENSE-APACHE; minimal-lexical-0.2.1/LICENSE-MIT; minimal-lexical-0.2.1/LICENSE.md
mipidsi | 0.10.0 | MIT | MIT | 790ebd28bd67addbccf41b1c0c188c26bb9f5bdcd91d4d6da9bd558e20d97a1d | https://static.crates.io/crates/mipidsi/mipidsi-0.10.0.crate | https://github.com/almindor/mipidsi | mipidsi-0.10.0/LICENSE
nb | 0.1.3 | MIT OR Apache-2.0 | MIT | 801d31da0513b6ec5214e9bf433a77966320625a37860f910be265be6e18d06f | https://static.crates.io/crates/nb/nb-0.1.3.crate | https://github.com/rust-embedded/nb | nb-0.1.3/LICENSE-APACHE; nb-0.1.3/LICENSE-MIT
nb | 1.1.0 | MIT OR Apache-2.0 | MIT | 8d5439c4ad607c3c23abf66de8c8bf57ba8adcd1f129e699851a6e43935d339d | https://static.crates.io/crates/nb/nb-1.1.0.crate | https://github.com/rust-embedded/nb | nb-1.1.0/LICENSE-APACHE; nb-1.1.0/LICENSE-MIT
nix | 0.29.0 | MIT | MIT | 71e2746dc3a24dd78b3cfcb7be93368c6de9963d30f43a6a73998a9cf4b17b46 | https://static.crates.io/crates/nix/nix-0.29.0.crate | https://github.com/nix-rust/nix | nix-0.29.0/LICENSE
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

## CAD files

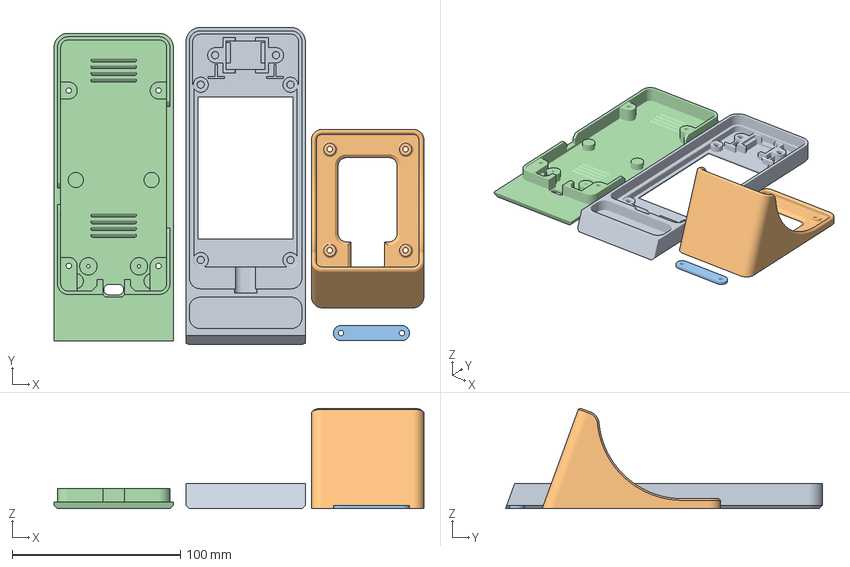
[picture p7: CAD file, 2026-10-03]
printable_3D_model/assembly.3mf
219.6 x 188.2 x 59.7 mm
FrontLid
Staender
HLK Mount
BackLid - NoBattery

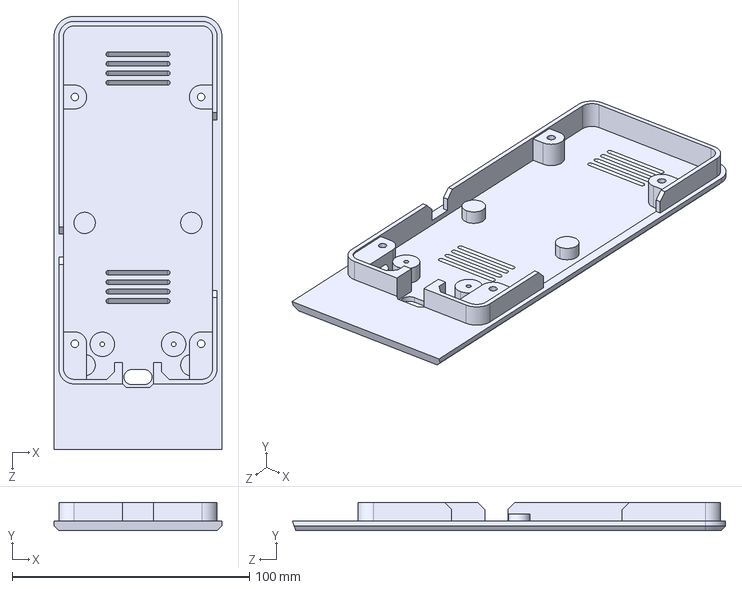
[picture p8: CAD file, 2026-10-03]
printable_3D_model/step/Back_Lid.STEP
70.9 x 12.0 x 182.8 mm

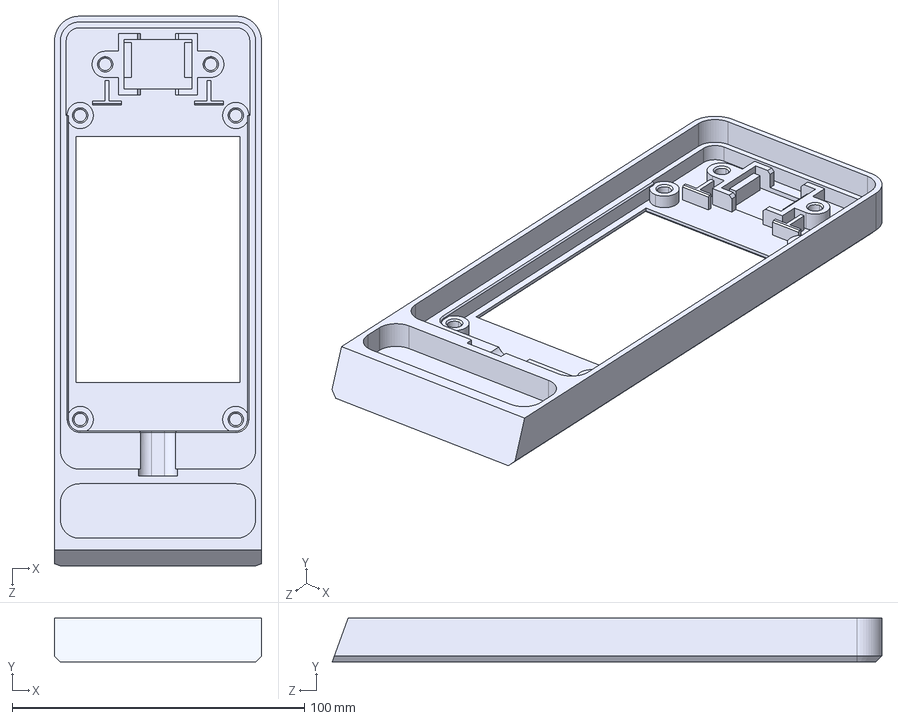
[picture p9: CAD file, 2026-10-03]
printable_3D_model/step/Front_Lid.STEP
70.9 x 15.0 x 188.2 mm

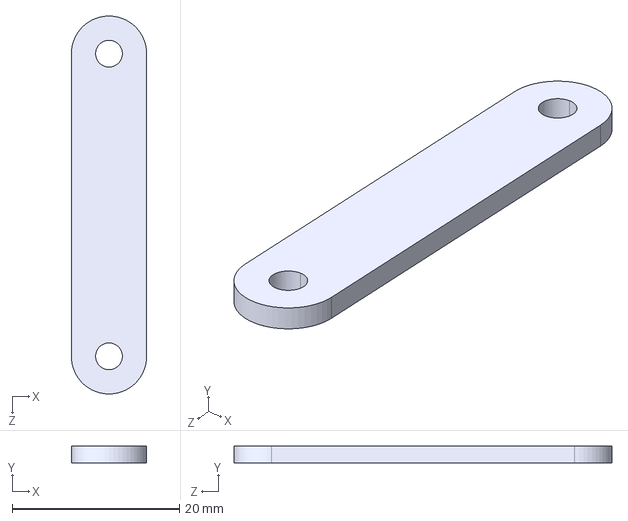
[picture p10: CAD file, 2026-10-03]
printable_3D_model/step/Mounting_Radar.STEP
9.00 x 2.00 x 45.1 mm

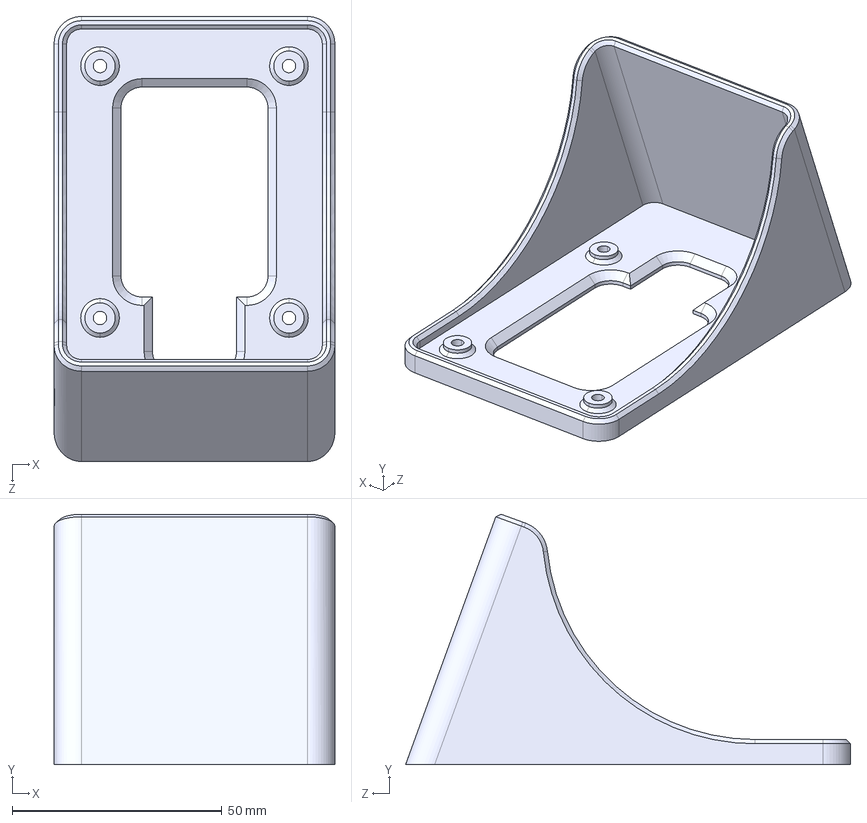
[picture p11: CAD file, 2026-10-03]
printable_3D_model/step/Stand.STEP
66.9 x 59.7 x 106.0 mm

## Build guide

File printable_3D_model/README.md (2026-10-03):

# 3D-printed enclosure and assembly

This enclosure holds the 4-inch ESP32 touchscreen display and an HLK-LD2410C presence radar in portrait orientation. A separate stand supports the assembled display and provides space for the USB power cable.

<p align="center">
Completed enclosure, front view
</p>

The screen in this photo shows an older version of the firmware.

## Model files

Print one of each of the four parts below. Use the 3MF project for the prepared print layout, or the individual STEP files to modify the parts in CAD or import them into a compatible slicer.

| File | Description |
| --- | --- |
| [assembly.3mf](assembly.3mf) | Print project containing all four parts, their print layout, saved slicer settings, and color modifiers for the cloud-and-sun emblem on the front lid. |
| [step/Front_Lid.STEP](step/Front_Lid.STEP) | Front enclosure with the display opening, the upper radar area, and insert locations for the enclosure and radar mount. |
| [step/Back_Lid.STEP](step/Back_Lid.STEP) | Rear enclosure with ventilation slots, USB cable clearance, enclosure fastening holes, and insert locations for the stand. |
| [step/Mounting_Radar.STEP](step/Mounting_Radar.STEP) | Retaining mount that secures the radar behind the upper front panel. |
| [step/Stand.STEP](step/Stand.STEP) | Desktop stand that attaches to the back lid with four screws. |

The STEP files contain the individual CAD geometry. The multicolor emblem setup is stored in the 3MF project.

## Parts and tools

Quantities are for one complete enclosure. Amazon links identify the supplied components. Select the listed size when a product offers several variants.

| Quantity | Description | Amazon ASIN | Amazon link |
| --- | --- | --- | --- |
| 10 | M3 threaded heat-set inserts, 4 mm long (M3L4) | B0GF3324TC | [Amazon](https://www.amazon.fr/-/en/dp/B0GF3324TC) |
| 1 | 4-inch CYD ESP32 touchscreen display matching this enclosure | B0FFZ599FJ | [Amazon](https://www.amazon.fr/-/en/dp/B0FFZ599FJ) |
| 1 | USB adapter for the cable routing shown below | B0C9TD16NP | [Amazon](https://www.amazon.fr/-/en/dp/B0C9TD16NP) |
| 1 | HLK-LD2410C presence radar module | B0H4434MG9 | [Amazon](https://www.amazon.fr/-/en/dp/B0H4434MG9) |
| 8 | M3×8 mm hex-socket screws (Allen/inbus) | Not supplied | — |
| 2 | M3×6 mm hex-socket screws (Allen/inbus) | Not supplied | — |
| 8 | M3 washers | Not supplied | — |

The 4-inch display is also available from its manufacturer and official seller, [Freenove](https://store.freenove.com/products/fnk0114?variant=45751420715206). Moreover, for the radar module's original product page, see [Hi-Link HLK-LD2410C](https://www.hlktech.net/index.php?id=1095).

You will also need a compatible 5V USB cable and power supply, a soldering iron with a suitable heat-set insert tip, and tools for cleaning printed edges. Wires with Dupont plugs between the radar and the screen are already included in the screen package delivered by Amazon.

## Printing and preparation

The settings saved in `assembly.3mf` are a reference for the original print:

| Setting | Saved value |
| --- | --- |
| Printer | Bambu Lab P1S |
| Nozzle diameter | 0.4 mm |
| Filament | PETG |
| Layer height | 0.2 mm |
| Walls | 5 |
| Infill | 15% |
| Supports | None in the supplied 3MF project |

Before slicing, select the correct printer and filament profiles for your equipment and review the orientation and color assignments. The project uses black, gray, white, and yellow filament assignments, including white for the cloud and yellow for the sun. Adapt the assignments to your available filament.

Print one front lid, one back lid, one radar mount, and one stand. Clean the mating edges, screw holes, display opening, and cable opening. Check the fit of the printed parts before installing the electronics.

## Assembly

The exploded views show how the display, radar, lids, adapter, and stand fit together. Dashed lines indicate the fastening points.

<p align="center">
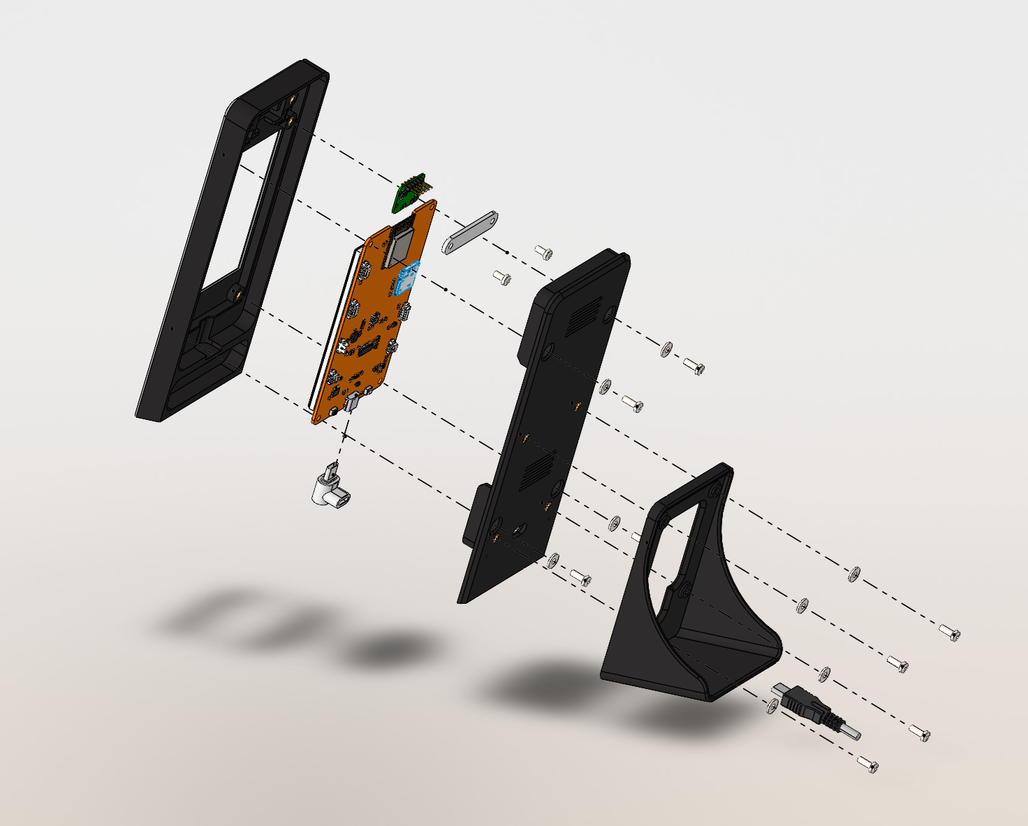
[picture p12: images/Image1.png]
Exploded assembly viewed from the rear

</p>

<p align="center">
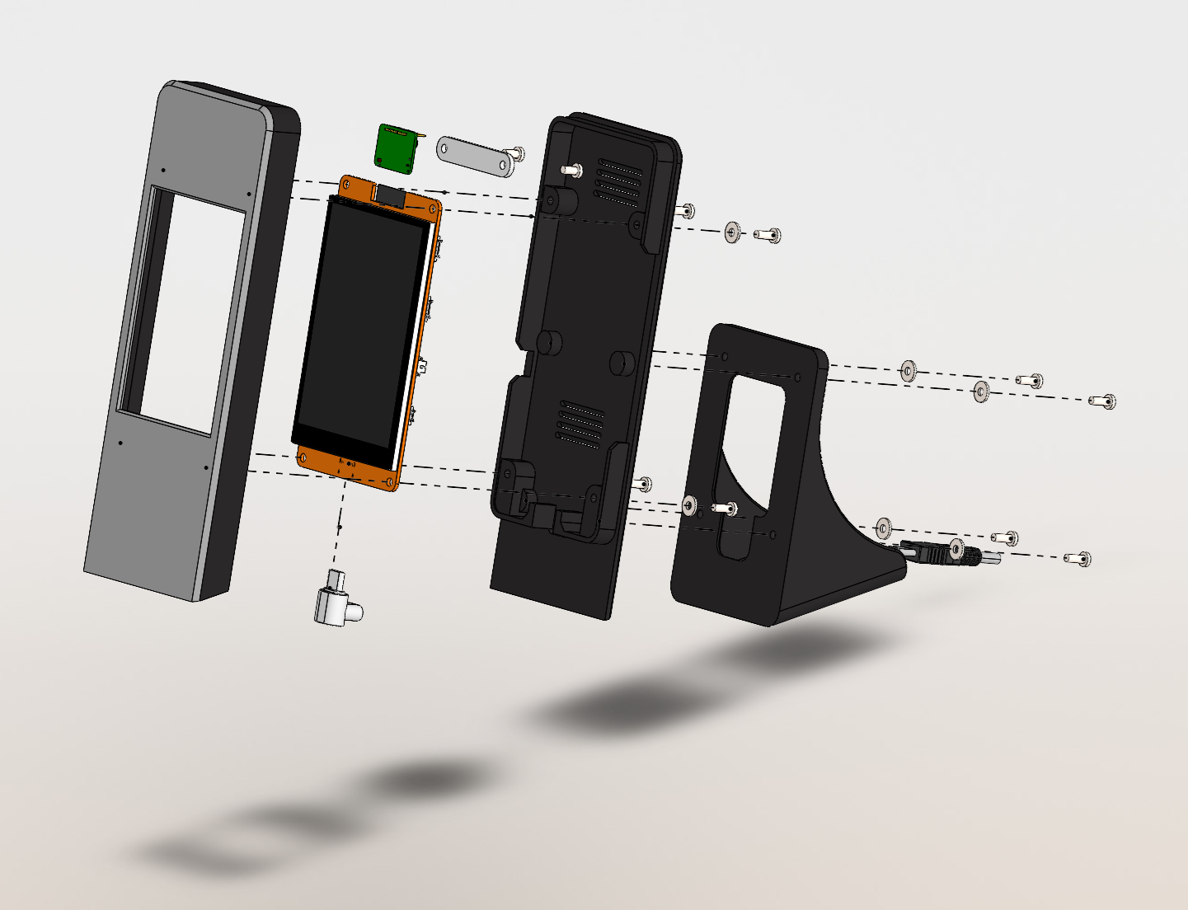
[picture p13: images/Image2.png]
Exploded assembly viewed from the front

</p>

### 1. Install the threaded inserts

Install all ten M3L4 heat-set inserts before fitting the electronics:

| Printed part | Insert locations | Quantity |
| --- | --- | --- |
| Front lid | Four enclosure fastening points and two radar-mount fastening points | 6 |
| Back lid | Four stand fastening points | 4 |

Support the part on a stable surface. Use the heated insert tip to press each insert straight into its recess, keeping it aligned with the screw axis and seated flush. Set the iron for the insert and printed material. Avoid pushing the insert through the part. Let the inserts and plastic cool before assembly.

### 2. Fit the radar

For this build, I desoldered the preinstalled straight 1×5 Dupont pin header from the radar module and soldered in a 90° pin header instead. This saves space inside the thin enclosure. Make this change before fitting the radar.

Place the radar in the upper area behind the front panel, above the display opening. Match its orientation to the exploded views, with the pin header accessible inside the enclosure. Fit the printed radar retaining mount and secure it to the two upper inserts with the **two M3×6 mm screws**.

### 3. Fit the display and connect the radar

With USB power disconnected, place the display behind the front opening, with the screen facing outward and its USB connector at the bottom. Align the board's four mounting holes with the enclosure fastening points. Support the board without pressing on the screen.

Keep USB power disconnected while wiring the HLK-LD2410C to the display board. Use four wires and identify each connection by its pin label rather than by wire color or connector orientation, especially after replacing the radar's pin header.

| Radar pin | Display board connection | Purpose |
| --- | --- | --- |
| VCC | Regulated 5 V supply shared with the display | Powers the radar. The supply must have more than 200 mA available for the radar in addition to the display's requirements. |
| GND | Display board GND | Provides a common ground for power and signals. |
| TX | GPIO35, labeled GP35 | Sends the radar's serial reports to the ESP32's UART1 receive input. |
| OUT | GPIO32, available as SDA on connector P4 | Sends the active-high presence signal to the ESP32. |
| RX | Leave unconnected | The current firmware does not send commands to the radar. |

Connect VCC and GND first, then TX and OUT according to the table. The radar's TX pin connects to the display's receive input, GPIO35. Keep the radar's RX pin unconnected and prevent it from touching other contacts. The radar is powered from 5 V, but its signal lines use 3.3 V logic. **Do not connect the 5 V supply to GPIO35 or GPIO32!**

The firmware receives serial reports at the radar's factory setting of **256000 baud, 8 data bits, no parity, and 1 stop bit (8N1)**. No sensor configuration is required for a module using these settings. Use the pins in the table: GPIO39 is used by the touchscreen, and UART0 is used by the USB connection for flashing and logs.

Before reconnecting USB power, check the pin labels, power polarity, and all connections for loose contacts or shorts. Insulate exposed wire connections. Route the wires inside the enclosure so that they clear the lid edges, screw holes, and ventilation slots.

### 4. Fit the USB adapter and back lid

Connect the USB adapter to the display's lower USB connector. Position it so the power cable can run toward the rear through the lower opening, as shown below.

<p align="center">
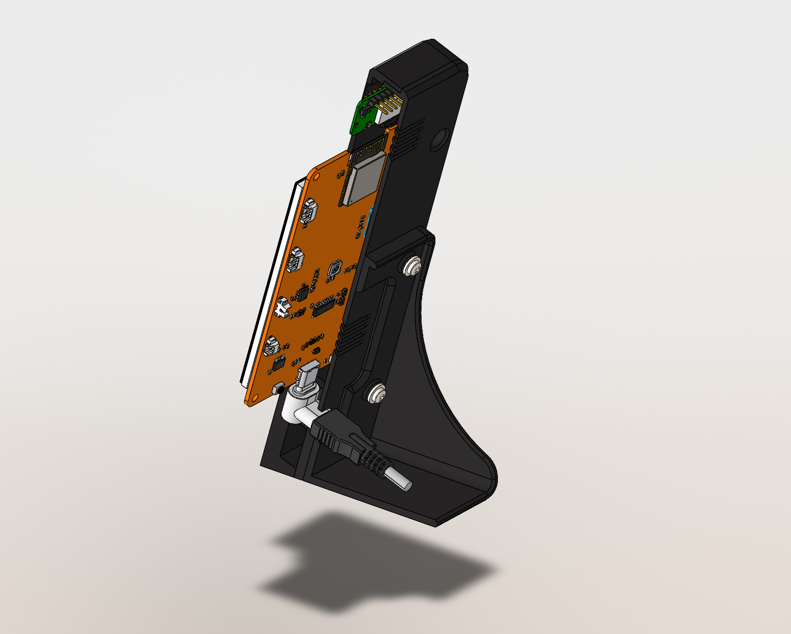
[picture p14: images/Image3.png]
Display, radar, USB adapter, and cable positioning from the rear

</p>

<p align="center">
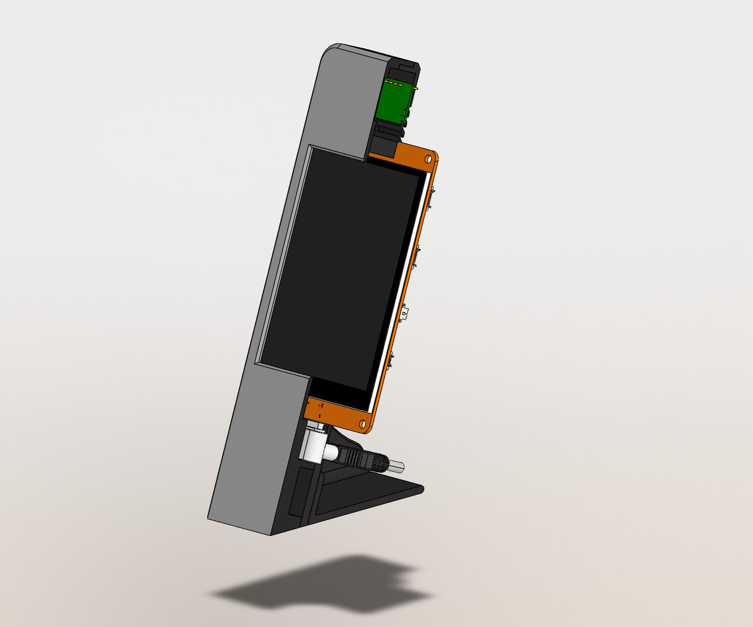
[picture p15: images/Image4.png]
Display and radar positioning behind the front lid

</p>

Fit the back lid over the display board, checking that the board's mounting holes remain aligned and that no wires are trapped. Secure the back lid to the front lid with **four M3×8 mm screws and four M3 washers**, following the four enclosure fastening lines in the exploded views. Tighten evenly until snug. Avoid overtightening the plastic or loading the display glass.

### 5. Attach the stand

Align the stand's four fastening holes with the four inserts in the back lid. Attach it with the remaining **four M3×8 mm screws and four M3 washers**. Route the USB cable through the space in the stand so it can exit toward the rear without pulling on the display connector.

<p align="center">
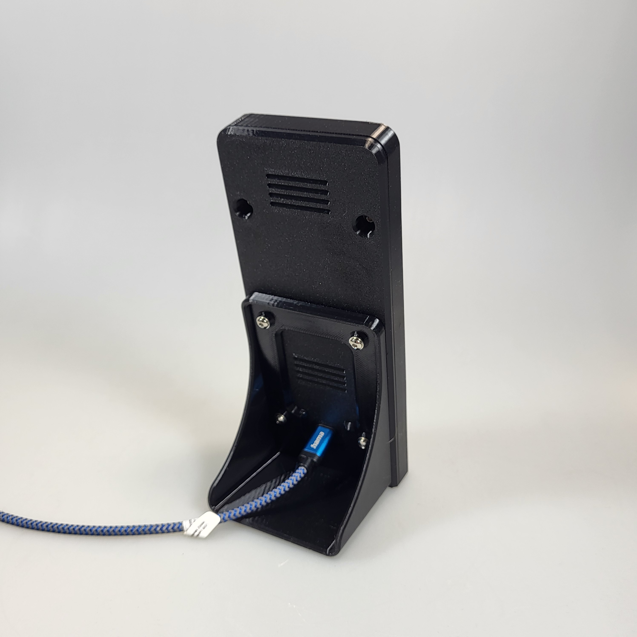
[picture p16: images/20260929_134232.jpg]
Completed enclosure, rear view with stand and USB cable

</p>

### 6. Check the finished assembly

- Confirm the display sits squarely in the front opening and the lids meet evenly.
- Check that all screws are snug, the stand is stable, and ventilation slots are clear.
- Check that the USB adapter and cable fit freely without pinching wires or straining the connector.
- Connect USB power and check the display and touch operation. Check radar presence detection after wiring and firmware setup.

See the [user guide](../USER_GUIDE.md) for firmware installation, touchscreen calibration, Wi-Fi setup and radar behaviour. The photos show the physical assembly. Their displayed firmware and interface may differ from the current version.

## Disclaimer

<b>This project and all associated files, documentation, and source code are provided “as is” without any express or implied warranties, including but not limited to the implied warranties of merchantability, fitness for a particular purpose, and non‑infringement. The author and contributors of this repository assume no responsibility or liability for any direct, indirect, incidental, or consequential damages that may occur through the use, modification, or distribution of the software and hardware designs contained herein. This includes, but is not limited to, hardware damage, data loss, malfunctioning devices, or personal injury that may arise from incorrect wiring, improper configuration, or misuse of the provided code and documentation. Users are encouraged to review, test, and verify all code before deploying it on any system. If you choose to use this project, you do so entirely at your own risk. By downloading, copying, modifying, or using any part of this project, you acknowledge that you have read, understood, and agree to this disclaimer.

The HLK-LD2410C radar module’s CE status is unknown to this project. The existence of an EU declaration of conformity or US regulatory compliance documentation has not been verified. Check your local laws and regulatory requirements before using the radar. Use it at your own risk.</b>

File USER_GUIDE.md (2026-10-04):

# User guide

The screenshots below come from the firmware renderer at the display's native 320 × 480 resolution and use synthetic weather, network, and location data. They show the controls you will use on the device.

Downloaded firmware should come in a release archive with its license notices and certificate source materials. Keep those accompanying materials when redistributing the images. See the [release licensing workflow](docs/FIRMWARE_RELEASE_LICENSES.md).

## Installing the firmware under Linux

Build the release firmware using the [Linux build instructions](README.md#building-on-linux). Run the commands below from the repository root. They target the supported classic ESP32 board with 4 MiB flash. Images built for an ESP32-S3 or a different display board are not suitable.

Activate the ESP-IDF Python environment created by the build. It is under `firmware/.embuild/espressif/python_env/`, with a directory name that depends on your Python version. For example, with Python 3.10:

```sh
. firmware/.embuild/espressif/python_env/idf5.5_py3.10_env/bin/activate
```

Convert the release ELF into an application image:

```sh
python -m esptool --chip esp32 elf2image \
  --flash_mode dio --flash_freq 40m --flash_size 4MB \
  --output firmware/target/xtensa-esp32-espidf/release/weather-forecast-firmware.bin \
  firmware/target/xtensa-esp32-espidf/release/weather-forecast-firmware
```

The release directory should now contain `bootloader.bin`, `partition-table.bin` and `weather-forecast-firmware.bin`. Connect the board by USB and check that your terminal user has read and write access to its serial port. Flash the images, replacing `/dev/ttyUSB0` with your board's port if necessary:

```sh
./flash.sh /dev/ttyUSB0
```

The script checks the chip, writes and verifies the images, then restarts the device. It preserves the settings and filesystem partitions. It does not erase the whole flash or program eFuses. The first start opens calibration if no valid calibration is saved.

## First start and Wi-Fi

On the first start, use the stylus to tap the four corner calibration targets, then the centre target. Lift the stylus between taps. The device saves a valid calibration for later starts. If verification fails, repeat the taps. A storage error is shown if the device cannot save the calibration.

The default settings are London, English, Celsius, 12-hour time, full brightness, night mode off, presence wake on and a five-minute screen-off timeout.

Tap **Set up new Wi-Fi**, choose your secured 2.4 GHz network, then enter its password and tap **Connect**. **Refresh** scans again. **Previous** and **Next** move through the network list. Use **Shift** for uppercase, **#+=** for symbols, and **Show password** to check your entry. The password keyboard uses ASCII in every language. A successful connection saves the network. After a restart, the device tries to reconnect automatically.

The device supports WPA2-Personal, WPA3-Personal and mixed WPA2/WPA3 networks. Passwords must contain 8–63 printable ASCII characters, including spaces. Hidden networks, open or WEP networks, enterprise authentication and raw hexadecimal pre-shared keys are not supported.

On startup, a saved network gets a 20-second connection attempt. If that fails, the screen shows the failure and retries every 30 seconds. A connected status means the device has joined Wi-Fi and obtained an IP address. It does not confirm internet access.

The new network replaces the saved one only after connection and saving succeed. Cancelling, scanning or a failed connection keeps the previous network. Storage errors are reported without automatically erasing saved data. **Credentials are stored unencrypted in the device's flash, so someone who can read the flash can recover the password!**

<p align="center">
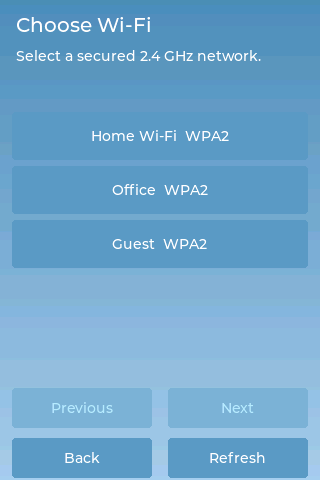
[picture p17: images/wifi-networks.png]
Wi-Fi network list with refresh and paging controls

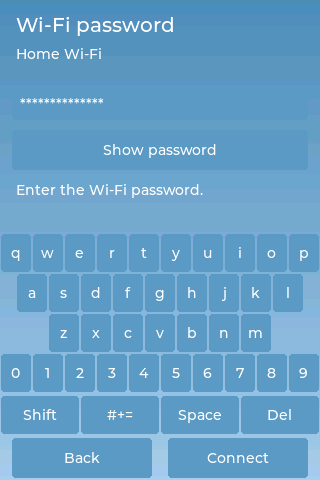
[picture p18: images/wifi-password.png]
Wi-Fi password entry with keyboard and Connect button

</p>

## Clock, Week, and Hours

The display opens on **Clock** after connecting. Tap the main content to cycle **Clock → Week → Hours → Clock**. The pages do not rotate automatically.

| Page | What it shows |
| --- | --- |
| Clock | Analogue and digital local time, local date, current temperature, weather symbol, and feels-like temperature. |
| Week | Today and the next six days, with minimum/maximum temperatures and mean daily precipitation probability. |
| Hours | The next seven full hours, with local forecast time, temperature, and precipitation probability. |

<p align="center">
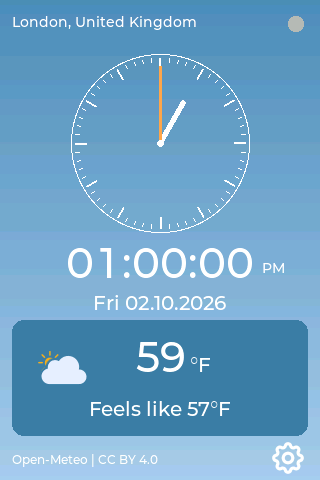
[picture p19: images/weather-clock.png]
Clock page with current weather and local time

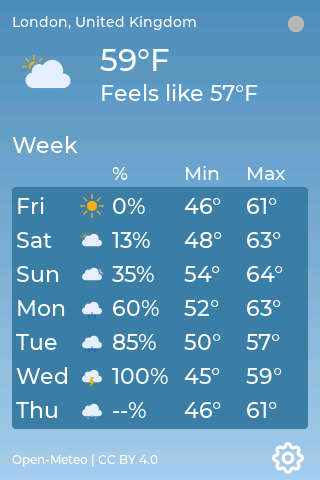
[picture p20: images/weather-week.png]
Week page with seven daily forecasts

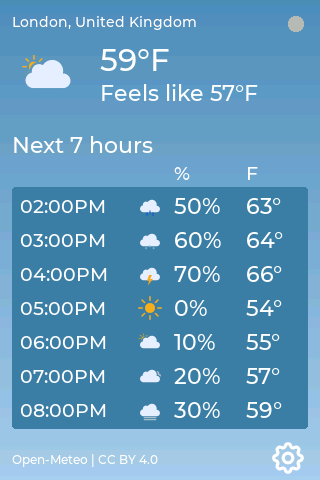
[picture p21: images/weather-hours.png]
Hours page with seven hourly forecasts

</p>

The location appears above the weather. The footer contains the weather source credit and a settings gear. Missing values appear as dashes. Status messages explain when weather is loading, unavailable or outdated. The Week percentage is the mean daily precipitation probability, rounded to a whole percentage. Hours shows the next seven full forecast hours after the current time.

All pages use the saved location's timezone, including daylight-saving changes. The clock waits for synchronised time and a known timezone. Before then, the analogue dial has no hands. Weather pages show the city and country, while Settings and search retain the full location name.

Forecasts refresh every ten minutes. A failed request is retried after one minute. A failed refresh keeps the previous forecast for the same location and marks it outdated. Data also becomes outdated after twenty minutes without a successful refresh. Missing future entries show dashes, and unknown weather codes use an unavailable symbol. Changing location clears the old forecast. Forecasts are not retained after a restart.

If Wi-Fi drops, the connection screen returns. Once reconnected, the device returns to the selected weather page. Closing Settings or waking the screen also keeps the selected page. A restart opens Clock.

## Settings and language

Tap the footer's gear to open **Settings**, or use **Settings** on the Wi-Fi failure screen. Tap a switch to turn its option on or off, or tap a button to open its choices. The controls work as follows:

<p align="center">
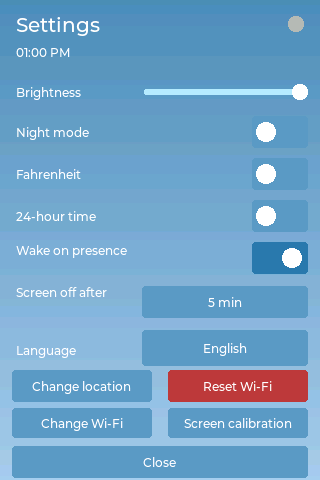
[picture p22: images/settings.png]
Settings with brightness, switches, language, and setup controls

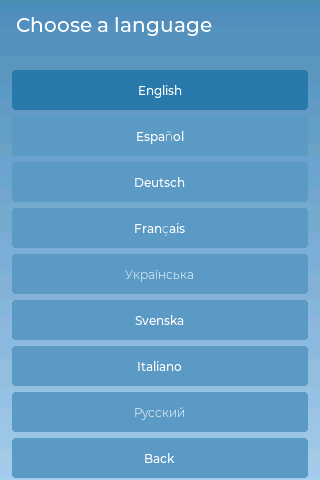
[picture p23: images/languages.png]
Language picker including Ukrainian

</p>

| Option | What it does |
| --- | --- |
| **Brightness** | Changes the screen's backlight brightness. Drag the slider left to dim it or right to brighten it. The screen previews the change while you drag and saves it when you release. Waking the screen restores this brightness. |
| **Night mode** | Enables nighttime screen blanking from 22:00 to 06:00 in your selected location's timezone. With a finite screen-off timeout, the same inactivity interval applies day and night. With **Never**, night mode can still turn the backlight off at night. Touch or enabled radar presence wakes it and overrides that night's schedule. It does not automatically light up at 06:00. This option does not change the brightness slider. |
| **Fahrenheit** | When on, displays temperatures in °F on all weather pages, including feels-like and minimum/maximum values. When off, uses °C. |
| **24-hour time** | When on, uses times such as **13:00**. When off, uses **01:00 PM**. Applies to the clock, hourly forecast, and time shown in Settings. Your location determines the timezone. |
| **Wake on presence** | Lets a connected radar keep the screen awake or wake it when someone is detected. When off, radar presence does not wake the screen or restart the inactivity timer. Touch still wakes it. |
| **Screen off after** | Chooses how long the screen stays lit without touch or enabled radar presence: **1**, **5**, **10**, or **30 minutes**. **Never** disables inactivity blanking, though night mode may still blank it. Only the backlight turns off. The clock and weather continue updating. See [Screen sleep and wake](#screen-sleep-and-wake). |
| **Language** | Tap the displayed language name to open the language picker, then tap a language to apply and save it immediately. Changes UI labels and messages and the default location-entry alphabet. It does not change your temperature units, time format, or saved location. The eight languages are English, Spanish, German, French, Ukrainian, Swedish, Italian, and Russian. |
| **Change location** | Opens city or postal-code search. Select a result and tap **Save** to update the forecast location and local timezone. See [Choose your location](#choose-your-location). |
| **Reset Wi-Fi** | Asks for confirmation before forgetting the saved network. Use this when you want the device to stop reconnecting to that network. Your preferences, location, and touchscreen calibration are kept. |
| **Change Wi-Fi** | Opens network selection so you can connect to a different network. The new credentials replace the saved network only after a successful connection and save. Cancelling or a failed attempt keeps the previous network. |
| **Screen calibration** | Opens instructions and a **Start** button to recalibrate touch if taps do not line up with controls. Tap four corner targets, then the centre, lifting the stylus between taps. BOOT cancels. A successful verification saves the new calibration. Cancelling or a failed attempt keeps the old one. |
| **Close** | Returns to the weather page you were viewing. It does not discard preference changes that have already been saved. |

Switches, language selection, and the screen-off timeout save as soon as you change them. There is no separate Save button for these preferences. Location changes require **Save**, and brightness saves when you release the slider. If saving a preference fails, the device restores its previous saved value and shows an error. An unreadable saved profile also shows an error and prevents preference changes from being saved. Existing legacy preferences can be imported without erasing them. An unsupported saved language selection falls back to English.

## Recalibrating touch

Use **Screen calibration** in Settings if taps no longer line up with controls. Read the instructions and tap **Start**, or **Back** to return. Tap the four corner targets and the centre verification target, lifting the stylus between taps. BOOT cancels calibration. Each target has a 60-second timeout, and invalid alignment offers a retry. The old calibration is kept until the new one passes verification and is saved.

You can also start recalibration by holding **BOOT for one second while the startup message is visible**. There is a three-second window after boot. Press it after startup begins. Holding BOOT while powering on or resetting selects the ESP32 download mode instead.

## Choose your location

In Settings, tap **Change location**. Enter a city or postal code, tap **Search**, choose the intended result, then tap **Save**. Check the region and country to distinguish places with the same name. Saving updates the weather location and its timezone. Search needs Wi-Fi and synchronised time.

<p align="center">
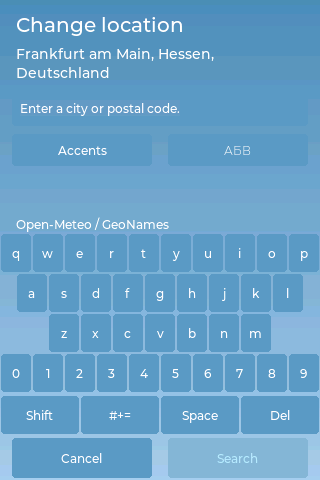
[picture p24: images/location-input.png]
City or postal-code input with alphabet and accent controls

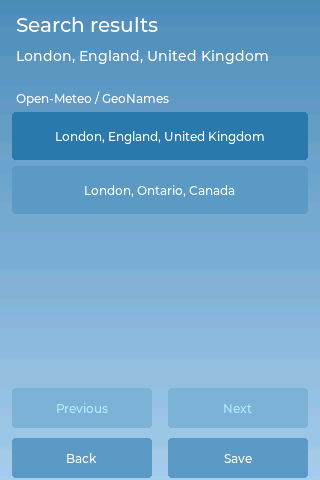
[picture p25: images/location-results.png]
Search results showing two locations named London

</p>

**Shift** changes letter case, **#+=** opens symbols, **Accents** opens accented letters, **Space** inserts a space, and **Del** deletes the last character. The **АБВ/ABC** button switches between Cyrillic and Latin without clearing your text. Ukrainian starts with its own Cyrillic alphabet, including **Ґ, Є, І, Ї** and an apostrophe. Russian starts with its alphabet, including **Ё/ё**. Other languages start with Latin input. The saved location is shown above the input field.

Search returns up to 15 results in the selected language. If it times out after ten seconds, check the connection and try again. Leaving the search screen cancels the pending search.

Search terms and location coordinates are sent to Open-Meteo. See its [terms and privacy information](https://open-meteo.com/en/terms) for provider logging details. The free public API is intended for non-commercial use. Commercial deployments need a suitable API plan and endpoint configuration.

## Screen sleep and wake

Tap **Screen off after** in Settings to choose **Never**, **1**, **5**, **10**, or **30 minutes**. The default is five minutes. When the inactivity timeout expires, the backlight turns off while the device keeps updating the clock and weather.

<p align="center">
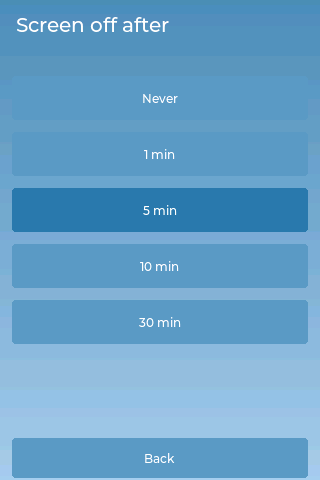
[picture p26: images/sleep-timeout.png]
Screen-off timeout choices from Never to 30 minutes

</p>

Touch wakes the screen. The first waking touch does not activate a control. Radar presence also wakes it when **Wake on presence** is enabled and a radar is connected. The current page is preserved on wake. **Night mode** uses 22:00–06:00 in the selected location's timezone. With a finite timeout, it uses the same inactivity interval. With **Never**, it can still blank the screen at night. Touch or enabled presence overrides that night's schedule. The screen stays dark after morning until you wake it. Night mode waits for synchronised time and a known location timezone before applying its schedule.

Touch and enabled radar presence restart the inactivity countdown. Changing the timeout also restarts it. Calibration keeps the screen awake with at least half brightness. Clock updates, forecast requests and Wi-Fi traffic do not keep it awake. Only the backlight turns off, so this uses more power than deep sleep.

If turning off the backlight fails, the screen remains lit and retries after one minute. If restoring it fails, another touch or presence detection can retry.

## Presence indicator

A small dot at the top right of Settings and Wi-Fi status pages shows radar status:

- Green means presence is detected through serial reports or the radar's OUT pin.
- Red means serial reports are arriving and no presence is detected.
- Grey means no current serial reports are arriving and OUT is inactive.

The indicator keeps updating even when **Wake on presence** is off. A grey dot can mean the radar is disconnected, has no power, is wired incorrectly or uses a different baud rate. A green dot can appear from OUT even without serial reports. The firmware expects the radar's factory settings and does not change them. See the [assembly guide](printable_3D_model/README.md#3-fit-the-display-and-connect-the-radar) for wiring.

## Other language examples

Ukrainian examples: [Clock](images/weather-clock-uk.png), [Week](images/weather-week-uk.png), [Hours](images/weather-hours-uk.png), [Settings](images/settings-uk.png) and [location keyboard](images/location-cyrillic-uk.png). Russian examples: [Clock](images/weather-clock-ru.png), [Week](images/weather-week-ru.png) and [Hours](images/weather-hours-ru.png).

## More information

See the [main README](README.md) for the project overview and Linux build instructions. The [firmware README](firmware/README.md) covers technical details, testing and screenshot generation. For the enclosure, see the [assembly guide](printable_3D_model/README.md).

# Disclaimer
<b>This project and all associated files, documentation, and source code are provided “as is” without any express or implied warranties, including but not limited to the implied warranties of merchantability, fitness for a particular purpose, and non‑infringement. The author and contributors of this repository assume no responsibility or liability for any direct, indirect, incidental, or consequential damages that may occur through the use, modification, or distribution of the software and hardware designs contained herein. This includes, but is not limited to, hardware damage, data loss, malfunctioning devices, or personal injury that may arise from incorrect wiring, improper configuration, or misuse of the provided code and documentation. Users are encouraged to review, test, and verify all code before deploying it on any system. If you choose to use this project, you do so entirely at your own risk. By downloading, copying, modifying, or using any part of this project, you acknowledge that you have read, understood, and agree to this disclaimer.

The HLK-LD2410C radar module’s CE status is unknown to this project. The existence of an EU declaration of conformity or US regulatory compliance documentation has not been verified. Check your local laws and regulatory requirements before using the radar. Use it at your own risk.</b>

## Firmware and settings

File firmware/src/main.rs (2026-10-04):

// ============================================================================= //
// File          : main.rs                                                       //
// License       : MIT                                                           //
// Created       : 2026-10-04                                                    //
// Last modified : 2026-10-04                                                    //
// Author        : Daniel Kharlamov                                              //
// Last editor   : Daniel Kharlamov <daniel.kharlamov@googlemail.com>            //
// ============================================================================= //
//                                                                               //
// Summary:                                                                      //
// --------                                                                      //
// ESP32 firmware startup and the main application loop.                         //
//                                                                               //
// Module:                                                                       //
// -------                                                                       //
// Initializes logging, storage, board peripherals, and background Wi-Fi and     //
// HTTP workers. Coordinates application events, touch input, settings           //
// persistence, forecast refreshes, synchronized time, radar presence, and       //
// backlight control. Schedules full or partial UI redraws and handles device    //
// errors.                                                                       //
// ============================================================================= //

//! ESP32 application entry point and main event loop.
//!
//! Coordinates background network and HTTP workers with touch, settings, radar,
//! backlight scheduling, and full or partial display updates.

use esp_idf_svc::{hal::peripherals::Peripherals, nvs::EspDefaultNvsPartition};
use std::{
    sync::{
        atomic::{AtomicBool, Ordering},
        mpsc, Arc,
    },
    thread,
    time::{Duration, Instant, SystemTime, UNIX_EPOCH},
};
use weather_forecast_firmware::{
    board::Board,
    location,
    model::{App, Command, Event, Page},
    network,
    screen::ScreenController,
    settings::{Overlay, Preferences, Settings},
    settings_store::Store,
    settings_ui::{self, Effect},
    touch::{TouchPhase, WizardResult},
    ui,
};

/// Starts firmware services and coordinates device events, weather, settings, touch,
/// presence, and rendering.
///
/// # Arguments
///
/// None.
///
/// # Returns
///
/// `anyhow::Result<()>` - Ok if the application returns normally; Err on unrecoverable
/// startup or device operations. Normal operation runs continuously.
///
/// # Errors
///
/// Propagates initialization, thread-spawn, and fallible device operations; recoverable
/// failures are reflected in application state.
fn main() -> anyhow::Result<()> {
    // Link the ESP-IDF compatibility patches required by the Rust service bindings.
    esp_idf_svc::sys::link_patches();
    // Route log messages through the SDK logger for device diagnostics.
    esp_idf_svc::log::EspLogger::initialize_default();
    // Release GPIO holds left by older firmware before acquiring HAL peripherals.
    Board::release_sleep_holds();
    // Keep ESP-IDF nonvolatile-storage partition or namespace handle in this local variable for the
    // following operations.
    let nvs = EspDefaultNvsPartition::take_with(false)
        .map_err(|_| anyhow::anyhow!("NVS initialization failed; storage was not erased"))?;
    // Keep persistent storage adapter used by this subsystem in this local variable for the
    // following operations.
    let store = Store::open(nvs.clone());
    // Keep result of opening and decoding saved preferences; failure enables read-only mode in this
    // local variable for the following operations.
    let loaded = store
        .as_ref()
        .map_err(|_| "Settings could not be read.")
        .and_then(|store| store.load(nvs.clone()));
    // Disable preference writes when loading failed, preserving unreadable storage instead of
    // overwriting it with defaults.
    let read_only = loaded.is_err();
    // Keep device preferences controlling location, language, units, brightness, and clock format
    // in this local variable for the following operations.
    let settings = loaded.unwrap_or_else(|_| Settings::default());
    // Keep the returned components: `board` holds initialized Freenove peripherals providing
    // display, touch, radar, and backlight access, `modem` holds remaining Wi-Fi modem peripheral
    // handed to the network worker in this local variable for the following operations.
    let (mut board, modem) = Board::new(
        Peripherals::take()?,
        nvs.clone(),
        settings.language,
        settings.brightness,
    )?;
    // Keep the returned components: `sender` holds initial Wi-Fi command sender, renamed for its
    // application role, `rx` holds Wi-Fi command receiver moved into the network worker in this
    // local variable for the following operations.
    let (sender, rx) = mpsc::channel();
    // Keep sending end of the Wi-Fi command channel in this local variable for the following
    // operations.
    let commands = sender;
    // Keep the returned components: `tx` holds Wi-Fi event sender moved into the network worker,
    // `events` holds Wi-Fi event receiver polled by the main loop in this local variable for the
    // following operations.
    let (tx, events) = mpsc::channel();
    // Keep shared indication that Wi-Fi has an assigned IP connection in this local variable for
    // the following operations.
    let online = Arc::new(AtomicBool::new(false));
    // Obtain an owned clone of shared Wi-Fi readiness handle moved into the connection worker;
    // reference-counted handles continue to share their underlying state.
    let network_online = online.clone();
    // Start the configured worker thread; the closure owns the captured handles and runs
    // independently of the UI loop.
    thread::Builder::new()
        .name("wifi".into())
        .stack_size(16384)
        .spawn(move || network::run(modem, nvs, rx, tx, network_online))?;
    // Keep the returned components: `requests` holds one-slot HTTP work queue preventing unbounded
    // pending searches, `request_rx` holds receiving end of the HTTP work queue moved into the
    // location worker in this local variable for the following operations.
    let (requests, request_rx) = mpsc::sync_channel(1);
    // Keep the returned components: `response_tx` holds HTTP result sender moved into the location
    // worker, `responses` holds HTTP result receiver polled by the main loop in this local variable
    // for the following operations.
    let (response_tx, responses) = mpsc::channel();
    // Keep whether SNTP has supplied trusted time for TLS and local clock calculations in this
    // local variable for the following operations.
    let synchronized = Arc::new(AtomicBool::new(false));
    // Obtain an owned clone of shared SNTP readiness handle moved into the HTTP worker;
    // reference-counted handles continue to share their underlying state.
    let http_sync = synchronized.clone();
    // Obtain an owned clone of shared Wi-Fi readiness handle moved into the HTTP worker;
    // reference-counted handles continue to share their underlying state.
    let http_online = online.clone();
    // Start the configured worker thread; the closure owns the captured handles and runs
    // independently of the UI loop.
    thread::Builder::new()
        .name("location".into())
        .stack_size(16384)
        .spawn(move || location::run(request_rx, response_tx, http_online, http_sync))?;
    // Keep application state used by navigation, preferences, weather, and rendering in this local
    // variable for the following operations.
    let mut app = App {
        // Initialize editable preferences and their saved rollback baseline from the supplied
        // value.
        preferences: Preferences::new(settings, read_only),
        ..App::default()
    };
    // Keep monotonic starting instant, independent of wall-clock corrections in this local variable
    // for the following operations.
    let started = Instant::now();
    // Keep backlight state machine retaining inactivity, night overrides, and hardware retry
    // deadlines in this local variable for the following operations.
    let mut screen = ScreenController::new(&app.preferences.current, 0);
    // Keep whether the entire visible page needs to be redrawn in this local variable for the
    // following operations.
    let mut dirty = true;
    // Keep whether the minute-only settings clock needs to be repainted in this local variable for
    // the following operations.
    let mut clock_dirty = false;
    // Keep whether the analog/digital weather clock needs a differential update in this local
    // variable for the following operations.
    let mut weather_clock_dirty = false;
    // Keep whether current weather or the forecast table needs a differential update in this local
    // variable for the following operations.
    let mut weather_dirty = false;
    // Keep whether the presence indicator changed and needs a small redraw in this local variable
    // for the following operations.
    let mut presence_dirty = false;
    // Keep whether touch I/O has entered the fatal error state in this local variable for the
    // following operations.
    let mut touch_failed = false;
    // Keep last whole monotonic second processed, preventing repeated clock work within one second
    // in this local variable for the following operations.
    let mut last_second = u64::MAX;
    // Keep next monotonic millisecond deadline for resolving an imported location's timezone in
    // this local variable for the following operations.
    let mut resolve_at = 0;
    // Keep identifier used to reject stale timezone-resolution responses in this local variable for
    // the following operations.
    let mut resolve_id = 0;
    // Keep processing events or samples until an explicit break, return, or channel shutdown ends
    // this loop.
    loop {
        // Keep elapsed monotonic milliseconds supplied to radar, touch, weather, and backlight
        // controllers in this local variable for the following operations.
        let milliseconds = started.elapsed().as_millis() as u64;
        // Keep elapsed monotonic seconds used by the Wi-Fi model's reconnect scheduler in this
        // local variable for the following operations.
        let now = milliseconds / 1000;
        // Keep combined radar presence used by the indicator and optional screen wake policy in
        // this local variable for the following operations.
        let presence = board.poll_radar(milliseconds);
        // Update whether the presence indicator changed and needs a small redraw using combined
        // radar presence used by the indicator and optional screen wake policy differs from
        // combined presence indication from UART reports and the OUT pin, retaining the accumulated
        // state for subsequent steps.
        presence_dirty |= presence != app.radar;
        // Set combined presence indication from UART reports and the OUT pin to combined radar
        // presence used by the indicator and optional screen wake policy.
        app.radar = presence;
        // Check whether elapsed monotonic seconds used by the Wi-Fi model's reconnect scheduler
        // differs from last whole monotonic second processed, preventing repeated clock work within
        // one second.
        if now != last_second {
            // Set last whole monotonic second processed, preventing repeated clock work within one
            // second to elapsed monotonic seconds used by the Wi-Fi model's reconnect scheduler.
            last_second = now;
            // Keep UTC Unix timestamp in seconds; an optional value is unavailable before time
            // synchronization in this local variable for the following operations.
            let epoch = if synchronized.load(Ordering::Relaxed) {
                // Produce the transformed value or entries produced by the closure.
                SystemTime::now()
                    .duration_since(UNIX_EPOCH)
                    .ok()
                    .map(|time| time.as_secs() as i64)
            } else {
                // Return no available value as the value of this block.
                None
            };
            // Keep prior state used to detect changes without redrawing unchanged content in this
            // local variable for the following operations.
            let previous = app
                .weather
                .range_key(&app.preferences.current, app.preferences.epoch);
            // Keep current state or measurement being prepared for display in this local variable
            // for the following operations.
            let current = app.weather.range_key(&app.preferences.current, epoch);
            // Keep whether the connected weather page is currently unobscured by a settings overlay
            // in this local variable for the following operations.
            let weather_visible = app.page == Page::Connected && app.preferences.overlay.is_none();
            // Check whether `weather_visible && previous != current`.
            if weather_visible && previous != current {
                // Marks weather dirty only when the connected weather page is visible.
                mark_weather_update(&app, &mut weather_dirty);
            }
            // Update whether the analog/digital weather clock needs a differential update using
            // whether the connected weather page is currently unobscured by a settings overlay and
            // view equals weather_forecast_firmware weather View Clock and local result for the
            // surrounding operation differs from local result for the surrounding operation,
            // retaining the accumulated state for subsequent steps.
            weather_clock_dirty |= weather_visible
                && app.weather.view == weather_forecast_firmware::weather::View::Clock
                && weather_forecast_firmware::weather::local(&app.preferences.current, epoch)
                    != weather_forecast_firmware::weather::local(
                        &app.preferences.current,
                        app.preferences.epoch,
                    );
            // Update whether the minute-only settings clock needs to be repainted using update time
            // result for the surrounding operation, retaining the accumulated state for subsequent
            // steps.
            clock_dirty |= app.preferences.update_time(epoch);
        }
        // Execute observe for backlight state machine retaining inactivity, night overrides, and
        // hardware retry deadlines.
        screen.observe(
            &app.preferences.current,
            app.preferences.epoch,
            milliseconds,
            app.preferences.overlay.is_some_and(|o| {
                matches!(
                    o,
                    Overlay::CalibrationIntro
                        | Overlay::CalibrationRunning
                        | Overlay::CalibrationError
                )
            }) || touch_failed
                || app.page == Page::Fatal,
            app.radar.present(),
            board.touch_pressed(),
        );
        // Visit each entry in try iter result for the surrounding operation; the loop binding
        // provides its value or index for this iteration.
        for event in events.try_iter() {
            // Keep overlay in this local variable for the following operations.
            let overlay = app.preferences.overlay;
            // Keep status displayed to the reader instead of silent failure in this local variable
            // for the following operations.
            let status = app.preferences.status;
            // Check whether an available handle result for the surrounding operation matches the
            // requested case.
            if let Some(command) = app.handle(event, now) {
                // Perform the best-effort operation and intentionally ignore its result: Deliver
                // the event or command to its worker/application channel; this send waits if
                // required by the channel.
                let _ = commands.send(command);
            }
            // Update whether the entire visible page needs to be redrawn using overlay is
            // unavailable or overlay differs from overlay or status displayed to the reader instead
            // of silent failure differs from status displayed to the reader instead of silent
            // failure, retaining the accumulated state for subsequent steps.
            dirty |= overlay.is_none()
                || overlay != app.preferences.overlay
                || status != app.preferences.status;
        }
        // Keep whether adopting the selected location cleared the old forecast and pending request
        // in this local variable for the following operations.
        let location_changed = app.weather.adopt(&app.preferences.current.location);
        // Update whether the entire visible page needs to be redrawn using whether adopting the
        // selected location cleared the old forecast and pending request and currently selected
        // Wi-Fi navigation page equals Connected state and overlay is unavailable, retaining the
        // accumulated state for subsequent steps.
        dirty |=
            location_changed && app.page == Page::Connected && app.preferences.overlay.is_none();
        // Visit each entry in try iter result for the surrounding operation; the loop binding
        // provides its value or index for this iteration.
        for response in responses.try_iter() {
            // Choose the appropriate path for parsed service result or hardware reply being
            // handled; each arm handles one supported case.
            match response {
                // Handle the location Response Forecast(id, location, result) case: apply the
                // state-specific behavior shown here.
                location::Response::Forecast(id, location, result) => {
                    // Keep whether the handled response or user action requires a display update in
                    // this local variable for the following operations.
                    let changed = app.weather.receive(
                        id,
                        &location,
                        result,
                        milliseconds,
                        app.preferences.epoch,
                    );
                    // Check whether whether the handled response or user action requires a display
                    // update.
                    if changed {
                        // Marks weather dirty only when the connected weather page is visible.
                        mark_weather_update(&app, &mut weather_dirty);
                    }
                    // Skip the remainder of this iteration and wait for or inspect the next input.
                    continue;
                }
                // Handle the location Response Locations(id, result) case: Execute locations for
                // editable preferences and their saved rollback baseline.
                location::Response::Locations(id, result) => app.preferences.locations(id, result),
                // Handle the location Response Timezone(id, Ok(location))                     if id
                // == resolve id                         &&
                // app.preferences.current.location.timezone.is empty()                         &&
                // location.name == app.preferences.current.location.name                         &&
                // location.latitude == app.preferences.current.location.latitude
                // && location.longitude == app.preferences.current.location.longitude case: apply
                // the state-specific behavior shown here.
                location::Response::Timezone(id, Ok(location))
                    if id == resolve_id
                        && app.preferences.current.location.timezone.is_empty()
                        && location.name == app.preferences.current.location.name
                        && location.latitude == app.preferences.current.location.latitude
                        && location.longitude == app.preferences.current.location.longitude =>
                {
                    // Set selected coordinates, location labels, and IANA timezone to selected
                    // coordinates, location labels, and IANA timezone.
                    app.preferences.current.location = location;
                    // Dispatches a settings effect to Wi-Fi, location search, or preference
                    // persistence.
                    apply(
                        Effect::Persist(app.preferences.current.clone()),
                        &mut app,
                        store.as_ref().ok(),
                        &commands,
                        &requests,
                    );
                }
                // Handle remaining cases with the fallback, preserving safe behavior for
                // unsupported or irrelevant input.
                _ => {}
            }
            // Set whether the entire visible page needs to be redrawn to the enabled state.
            dirty = true;
        }
        // Check whether `app.preferences.current.location.timezone.is_empty() &&
        // !app.preferences.read_only && milliseconds >= resolve_at &&
        // online.load(Ordering::Relaxed) && synchronized.load(Ordering::Re`.
        if app.preferences.current.location.timezone.is_empty()
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

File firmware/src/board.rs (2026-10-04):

// ============================================================================= //
// File          : board.rs                                                      //
// License       : MIT                                                           //
// Created       : 2026-10-04                                                    //
// Last modified : 2026-10-04                                                    //
// Author        : Daniel Kharlamov                                              //
// Last editor   : Daniel Kharlamov <daniel.kharlamov@googlemail.com>            //
// ============================================================================= //
//                                                                               //
// Summary:                                                                      //
// --------                                                                      //
// ESP32 board initialization, display, touch, and radar access.                 //
//                                                                               //
// Module:                                                                       //
// -------                                                                       //
// Initializes the shared SPI display and touch controller, backlight, radar,    //
// and board pins. Loads or performs touch calibration, maps touch events, and   //
// exposes full and partial UI rendering, brightness control, and radar polling  //
// to the application.                                                           //
// ============================================================================= //

//! Freenove ESP32 board peripherals and device UI integration.
//!
//! Initializes the LCD, shared-bus touch controller, calibration storage, radar,
//! and PWM backlight, and exposes their operations to the application loop.

use crate::{
    i18n::Language,
    model::App,
    touch::{self, Calibration, Press, RawPoint},
    ui,
};
use esp_idf_svc::{
    hal::{
        delay::Ets,
        gpio::{Input, Output, PinDriver, Pull},
        ledc::{config::TimerConfig, LedcDriver, LedcTimerDriver, LowSpeed},
        peripherals::Peripherals,
        spi::{
            config::{Config, DriverConfig},
            SpiDeviceDriver, SpiDriver,
        },
        units::Hertz,
    },
    nvs::{EspDefaultNvs, EspDefaultNvsPartition},
};
use mipidsi::{
    interface::SpiInterface,
    options::{ColorInversion, ColorOrder, Orientation},
    Builder,
};
use std::{
    sync::Arc,
    thread,
    time::{Duration, Instant},
};

/// ST7796 display initialization for the Freenove board.
mod display;
use display::FreenoveSt7796;
type Spi = SpiDeviceDriver<'static, Arc<SpiDriver<'static>>>;
pub type Lcd = mipidsi::Display<
    SpiInterface<'static, Spi, PinDriver<'static, Output>>,
    FreenoveSt7796,
    mipidsi::NoResetPin,
>;
pub struct Board {
    // Combined presence indication from UART reports and the OUT pin. Stored as
    // crate::radar::device::Radar.
    radar: crate::radar::device::Radar,
    // Initialized 320-by-480 ST7796 display with the board's portrait colour/orientation settings.
    // Stored as Lcd.
    lcd: Lcd,
    // Reusable old/new strip buffers enabling changed-pixel display updates. Stored as
    // crate::weather_ui::ClockBuffer.
    clock_buffer: crate::weather_ui::ClockBuffer,
    // XPT2046 SPI device, configured for 2.5 MHz bidirectional sampling. Stored as Spi.
    touch: Spi,
    // GPIO27 PWM channel controlling LCD illumination. Stored as LedcDriver<'static>.
    backlight: LedcDriver<'static>,
    // Retained LEDC timer handle needed by the backlight channel. Stored as
    // Arc<LedcTimerDriver<'static, LowSpeed>>.
    _timer: Arc<LedcTimerDriver<'static, LowSpeed>>,
    // GPIO0 active-low BOOT button requesting recalibration or cancelling the wizard. Stored as
    // PinDriver<'static, Input>.
    boot: PinDriver<'static, Input>,
    // GPIO36 active-low touch interrupt; assertions require sample validation before actions.
    // Stored as PinDriver<'static, Input>.
    touch_irq: PinDriver<'static, Input>,
    // GPIO4 output held low to silence the board's audio path. Stored as PinDriver<'static,
    // Output>.
    _audio: PinDriver<'static, Output>,
    // Touch_cal NVS namespace used to persist the portrait mapping. Stored as EspDefaultNvs.
    calibration_store: EspDefaultNvs,
    // Active mapping from raw touch samples to portrait screen pixels. Stored as Calibration.
    calibration: Calibration,
    // Touch debouncer that suppresses repeated actions during a held gesture. Stored as Press.
    press: Press,
}
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

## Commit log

2026-10-03 chore: initialize repository ignore rules
    Exclude build artifacts, local ESP-IDF tools, device secrets, and flash backups. Keep Cargo.lock tracked.
2026-10-03 feat: add ESP32 weather display firmware
    Implement weather forecasts, location search, Wi-Fi setup, multilingual settings, touch input, persistent preferences, and presence-controlled display behaviour. Include host tests and rendering prev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
    [partitions.csv]
2026-10-03 feat: add printable enclosure and stand models
    Include enclosure, stand, and radar mounting models together with printing, assembly, and wiring instructions.
    [Back_Lid.STEP, Front_Lid.STEP, Mounting_Radar.STEP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]
2026-10-03 feat(ui): enlarge settings gear and touch target
    Increase the settings gear from 32 to 38 pixels and its touch target from 44 to 53 pixels to improve finger access on Clock, Week, and Hours screens.
    Regenerate the alpha mask from the pinned SVG, update its attribution notice, and reserve the enlarged footer area from weather-page cycling. Extend hit tests to cover target edges across all views a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
    Validation: 76 host library tests and 9 preview tests passed; generated asset check passed. Release firmware built and flashed with verified image hashes.
2026-10-03 docs: refresh weather screenshots with larger settings gear
    Regenerate the Clock, Week, and Hours screenshots in English, Ukrainian, and Russian from the updated firmware renderer. Rebuild the README overview from the English screenshots.
    Verify all nine weather screenshots match their rendered previews and the overview contains the corresponding pages without resizing. Inspect the footer for clipping and overlap.
2026-10-04 docs: declare third-party sources and dependency licences
    Add the dated third-party declaration covering fonts, symbols, display code, platform libraries, certificate data, weather services and build tools.
    Record 194 Rust dependency versions with licence metadata and checksums, plus ESP-IDF submodule revisions and licence references. Update the README with concise credits and links to the detailed decl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
    [third-party-rust-2026-10-04.csv]
2026-10-04 docs: explain board drivers and sensor input handling
    Document hardware setup, display transfers, radar frame parsing, backlight state transitions, and touch filtering and calibration. Describe function arguments and return values, and add conventional 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
2026-10-04 docs: describe application services and settings persistence
    Document application state, Wi-Fi workers, location requests, forecast validation, and preference storage. Explain function contracts and the internal handling of cancellation, retries, malformed data, and persistence failures, including the corresponding unit tests. Preserve executable code and existing attribution.
    [weather.rs]
2026-10-04 docs: document firmware entry points and host preview
    Document library modules, build integration, device initialization, the main event loop, and host preview generation. Explain worker ownership, startup failures, preview fixtures, and drawing operations. Use Rustdoc for API documentation and ordinary line comments for implementation details; preserve executable code.
    [main.rs]
2026-10-04 ui: enlarge analog clock and lower digital time
    Increase the analog dial and hand lengths by approximately 20 percent and reposition the dial within the existing clock region. Match the orange seconds hand to the minute hand's three-pixel stroke, move digital digits closer to the date, and place AM/PM beside the time.
    Update cardinal geometry and digital-cell stability checks and add a rendered hand colour and width test. Retain one tick per second, existing differential rendering, and clock buffer sizes.
    Validation: 77 library tests and 9 preview rendering tests passed. ESP32 release build and flash checksum verification succeeded.
2026-10-04 license: relicense project code from GPL-3.0-only to MIT
    Replace the project license with MIT and update Rust source headers, Cargo metadata, documentation, and project-maintained asset notices consistently.
    Document that previously granted GPL rights remain in effect. Preserve third-party licenses and copyright notices, and update the firmware distribution guidance for the MIT license.
    Validation: git diff --check passed; Rust changes affect comments only, and upstream asset and license files remain unchanged.
    [board.rs, main.rs]
2026-10-04 ci: build and publish complete firmware release archives
    Build locked ESP32 firmware on validated version tags using pinned ESP tooling and GitHub Actions revisions. Discover the active application and SDK artifacts from Cargo output, collect matching lice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
    Upload test artifacts for manual runs without publishing. For tag runs, create a draft release and publish after uploading both complete firmware archives and checksums; preserve existing releases an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
    Validation: offline licensing check, all 31 t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
